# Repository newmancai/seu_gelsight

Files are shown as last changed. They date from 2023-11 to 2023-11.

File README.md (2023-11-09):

# Gelsight for Baxter Modified Robots

该资源库包含东南大学GelSight的制作、baxter改装机械手模型和采集数据集的c代码。这些代码可实现基本功能，例如查看和保存来自这些设备的数据（图像或视频）。

指导老师：东南大学钱堃

## Gelsight制作

参考gelsight与digit下的Gelsight制作说明
4led.SLDPRT为支架模型

## baxter机械手改装

参考baxter改装模型
gripper_modified_asm.stp为本次使用的改装机械手

## 采集数据集

### requirements

```sudo
sudo apt install ffmpeg
sudo apt install gpac
```

### Linux

``Python 3.8 or above``

### 运行

连接上锐尔摄像头

```sudo
ls /dev/video*
```

查看最新的两个路径（如video2,video3）
将video/encode_video.c中的摄像头的设备文件更改为/dev/video2

```sudo
cd video
gcc -g -O0 encode_video.c -lavformat -lavutil -lavdevice  -lavcodec -o encode_video.exe
./encode_video.exe或者(python photo.py)
```

下面是瓶子全空摇晃采集的视频
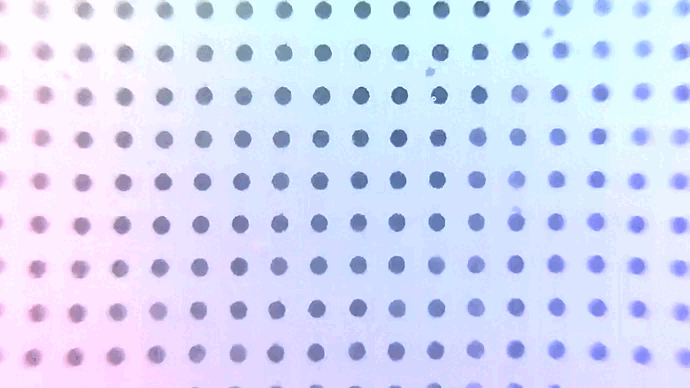
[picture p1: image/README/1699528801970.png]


## 联系我们

本软件包为东南大学大四16个课时课程设计的参考。如有任何问题/意见/建议，请联系 213203742@seu.edu.cn

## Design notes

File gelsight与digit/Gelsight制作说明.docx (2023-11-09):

Gelsight制作说明

一、材料购买

材料 | 用途 | 购买链接 | 备注
AB胶 | 透明膜制作
白色油墨、固化剂、稀释剂 | 膜白色表面涂层 | https://item.taobao.com/item.htm?spm=a1z09.2.0.0.4a312e8dLXXJ9j&id=594951473152&_u=b2095hi08209b4
3*3cm亚克力板 | 支撑 | https://item.taobao.com/item.htm?spm=a1z09.2.0.0.4a312e8dLXXJ9j&id=571400732683&_u=b2095hi08252ef | 3mm（优先），4mm
支撑结构 | 3D打印 | https://item.taobao.com/item.htm?spm=a1z09.2.0.0.4a312e8dLXXJ9j&id=660721591383&_u=b2095hi08253ca
5V灯带 | 照明 | https://item.taobao.com/item.htm?spm=a1z09.2.0.0.4a312e8dLXXJ9j&id=713155284856&_u=b2095hi08211f5
杜邦线 | 连接线
鱼眼相机 | 摄像头 | https://item.taobao.com/item.htm?spm=a1z09.2.0.0.4a312e8dLXXJ9j&id=525170536877&_u=b2095hi082c7ce | 无畸变镜头
PH2.0接线 | 摄像头连接线 | https://item.taobao.com/item.htm?spm=a1z09.2.0.0.4a312e8dLXXJ9j&id=18844977013&_u=b2095hi082d0dc
Usb公头4芯 | 摄像头连接线 | https://detail.tmall.com/item.htm?id=626045240070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 | 红5V黑GND绿DP白DM（仅对应购买链接）
小螺栓 | 固定摄像头与支撑结构
大螺栓 | 固定支撑结构与机器人手爪

注：购买链接仅为可用链接

二、膜制作

1、透明膜制作

AB胶1:1混合，搅拌，使用针管吸取混合溶液至模具中（6ml对应膜厚8mm），静置消除气泡，气泡消除后烤箱90℃加热30min

2、膜白色表面涂层

白色油墨与稀释剂1:4混合，搅拌，加入1滴固化剂，使用喷枪均匀喷涂在膜不平整的一面（透明膜制作时与空气接触的面），晾干

3、连接亚克力板

未喷涂白色涂层的面与亚克力板压紧，确保接触面无气泡

三、支撑结构

1、3灯带支撑结构

支撑摄像头：见附件3led.SLDPRT 3led.STL

保护摄像头：见附件protect.STL（stl文件尺寸与实际尺寸相比小10倍，打印时需放大）

2、4灯带支撑结构

支撑摄像头：见附件4led.SLDPRT 4led.STL（本次未上传）

保护摄像头：同上

注：实测发现，支撑摄像头结构中亚克力板的固定结构对于3D打印强度要求较高，否则亚克力板卡进固定结构时会使得固定结构折断

四、组装（以3灯带为例）

1、亚克力板卡入对应固定结构

2、5V灯条正*3、USB线5V、摄像头PH2.0接线5V焊接在一起

3、5V灯条负*3、USB线GND、摄像头PH2.0接线GND焊接在一起

4、摄像头PH2.0接线DP与USB线DP线焊接在一起、摄像头PH2.0接线DM与USB线DM线焊接在一起

5、灯带布局：红色灯带与蓝色灯带相对

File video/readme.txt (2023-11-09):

sudo apt install gpac
sudo apt install ffmpeg
gcc -g -O0 encode_video.c -lavformat -lavutil -lavdevice  -lavcodec -o encode_video.exe
./encode_video.exe或者(python photo.py)

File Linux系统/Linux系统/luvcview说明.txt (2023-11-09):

在桌面Linux系统上可直接从网络获取luvcview应用
如在ubuntu系统： apt-get install luvcview
运行：luvcview -d /dev/video0 -s 1280x720

查看luvcview的参数：luvcview --help

在PC机编译luvcview源码：
解压luvcview_0.2.4.orig.tar.gz
执行make

需要系统里有X11和SDL库，根据系统版本不同，可能要修改头文件：
#include <linux/videodev.h>  -->   #include <linux/videodev2.h>

其中v4l2uvc.c是最经典的V4L2代码，建议开发者直接拿这个文件中的接口函数使用，参见我们写的“MJPEG录像代码”

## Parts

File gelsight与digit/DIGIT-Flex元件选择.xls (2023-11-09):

备注 | Name | Description | Designator | Quantity | Manufacturer 1 | Manufacturer Part Number 1 | 最终选择 | 来源
数量与DIGIT实物不太符合，实物贴了5个 | ARGB1313HS | ARGB1313HS | D1, D2, D3 | 3 | Stanley Electric | ARGB1313HS-TR | ARGB1313HS-TR | https://item.taobao.com/item.htm?spm=a1z09.2.0.0.e8cd2e8d9dXkha&id=550657882868&_u=b2095hi0825007
 | DF37B-16DP |  | P1 | 1 | Hirose | DF37B-16DP-0.4V(53) | DF37B-16DP-0.4V | https://item.taobao.com/item.htm?spm=a1z09.2.0.0.e8cd2e8d9dXkha&id=562808093080&_u=b2095hi0820544

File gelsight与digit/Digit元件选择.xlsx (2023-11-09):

备注 | Comment | Description | Designator | Manufacturer1 | ManufacturerPartNumber1 | 元件编号 | 元器件来源 | 购买链接
 | MCR01MZPJ103 | ChipResistor,10KOhm,+/-5%,63mW,-55to155degC,0402(1005Metric),RoHS,TapeandReel | R2,R3,R6 | Rohm | MCR01MZPJ103 | C881063 | 立创商城
 | 100nF35V | 100nF35V±20% | C1,C3,C4,C6,C7,C8,C10,C11,C12,C13,C17,C19,C21,C22,C23,C25,C26 | TDK | C1005X7R1V104M | C181044 | 立创商城
 | 1uF6.3V | 1uF6.3V±10% | C16,C18,C20,C27,C28,C29,C30 | KyoceraAVX | 04026D105KAT2A | C5240378 | 立创商城
编号（C4355529）对应的器件丝印是（FT900Q-C-T），收到实物丝印是（FT900Q），售卖者表示正版 | FT900Q-C-R | FT900EmbeddedMicrocontroller,supportbothCANBusandEthernetfeatures,-40to+85degC,100-PinQFN,Pb-Free,TapeandReel | U1 | FTDI | FT900Q-R | C4355529 | 邮寄 | 微信：HLJ07035758
 | OVM7692 | CMOSwithProcessorImageSensor640Hx480V1.75µmx1.75µm | U2 | OmniVisionTechnologies | OVM7692-RAAA | C9900025065 | 邮寄 | https://item.taobao.com/item.htm?spm=a1z09.2.0.0.e8cd2e8d9dXkha&id=696075605241&_u=b2095hi08268cc
该选型可能错误，见文档说明 | ABM10-25.000MHZ-D30-T3 | 12MHz±25ppmCrystal18pF150Ohms4-SMD,NoLead | X1 | ECSInternational | ECS-120-18-36-AGM-TR | C117876 | 立创商城
 | 1KΩ5% | 1KΩ0.063W±5% | R1,R13,R14 | Yageo | RC0402JR-071KL | C11702 | 立创商城
 | DF37NB-16DS-0.4V | 16PositionConnectorReceptacle,CenterStripContactsSurfaceMountGold | P1 | Hirose | DF37NB-16DS-0.4V(51) | C2764729 | 邮寄 | 产品已下架
 | AP7343-33W5-7 | LinearVoltageRegulatorIC1Output300mASOT-25 | U3 | DiodesIncorporated | AP7343-33W5-7 | C460383 | 立创商城
 | 82Ω5%0.063W | 82R0.063W±5% | R9 | Panasonic | ERJ-2GEJ820X | C352387 | 立创商城
 | 18pF10V | 18pF10V±10% | C14,C15 | VishayVitramon | VJ0402A180KXQCW1BC | C1883107 | 邮寄 | https://item.taobao.com/item.htm?spm=a1z09.2.0.0.e8cd2e8d9dXkha&id=732051831113&_u=b2095hi082584e
 | 10uF6.3V | 10uF6.3V±20% | C2,C5 | TDK | C1005X5R0J106M050BC | C15525 | 立创商城
 | 270Ω5%0.063W | 270R0.063W±5% | R8,R10,R12 | Panasonic | ERJ-2GEJ271X | C911980 | 立创商城
 | 12KΩ1%0.063W | 12KΩ0.063W±1% | R4,R5 | Yageo | RC0402FR-0712KL | C881068 | 立创商城
 | 4.7uF10V | 4.7uF10V±10% | C9,C24 | KEMET | C0603C475K8PACTU | C380324 | 立创商城
编号（C232592）对应的器件丝印是（BC847CDXV6T1G），收到实物丝印是（1GY） | BC847CDXV6T5G | DualGeneralPurposeTransistors,NPN,6-PinSOT-563,Pb-Free,TapeandReel | Q1,Q2 | ONSemiconductor | BC847CDXV6T1G | C232592 | 邮寄 | 产品已下架
 | 100Ω5%0.063W | 100R0.063W±5% | R7 | VishayDale | CRCW0402100RJNED | C176111 | 立创商城
 | 150Ω5%0.063W | 150R0.063W±5% | R11 | VishayDale | CRCW0402150RJNED | C881296 | 立创商城
 | LQM18PN3R3MGHD | Inductor | L1,L2,L3 | Murata | LQM18PN3R3MGHD | C383399 | 立创商城
编号（C125810）对应的器件丝印是（LP3992IMFX-1.5/NOPB），收到实物丝印是（LFHB） | LP3992IMFX-1.5/NOPB | Micropower1.5VCMOSVoltageRegulatorwithShutdownControl,5-pinSOT-23,Pb-Free | U4 | TINationalSemiconductor | LP3992IMFX-1.5/NOPB | C125810 | 邮寄 | https://item.taobao.com/item.htm?spm=a1z09.2.0.0.e8cd2e8d9dXkha&id=708270094718&_u=b2095hi0829e42
 | USB3140-30-0230-1-C | MicroUSBReceptacle,TypeB,SMT,Vertical,withThrough-HoleShellStakes,-30to85degC,5-PinSMD,RoHS,TapeandReel | J1 | GlobalConnectorTechnology | USB3140-30-0230-1-C | C9900024888 | 邮寄 | https://item.taobao.com/item.htm?spm=a1z09.2.0.0.e8cd2e8d9dXkha&id=708983181332&_u=b2095hi0826603

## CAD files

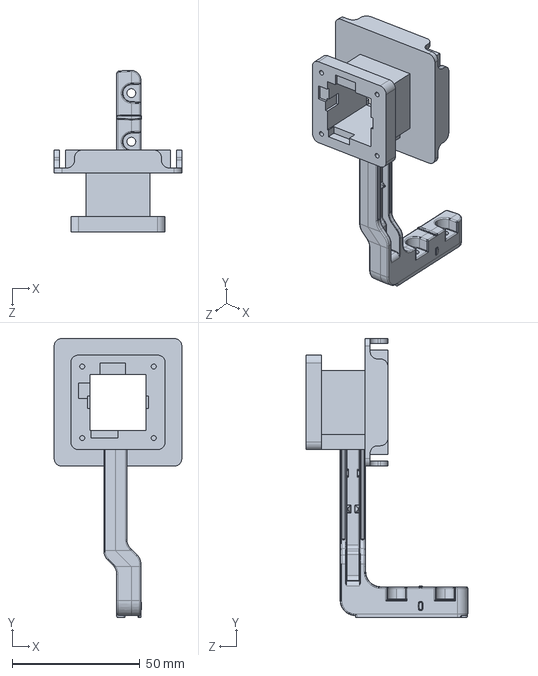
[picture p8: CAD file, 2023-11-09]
baxter改装模型/baxter改装模型/gripper_modified_asm.STEP
50.0 x 109.2 x 63.2 mm

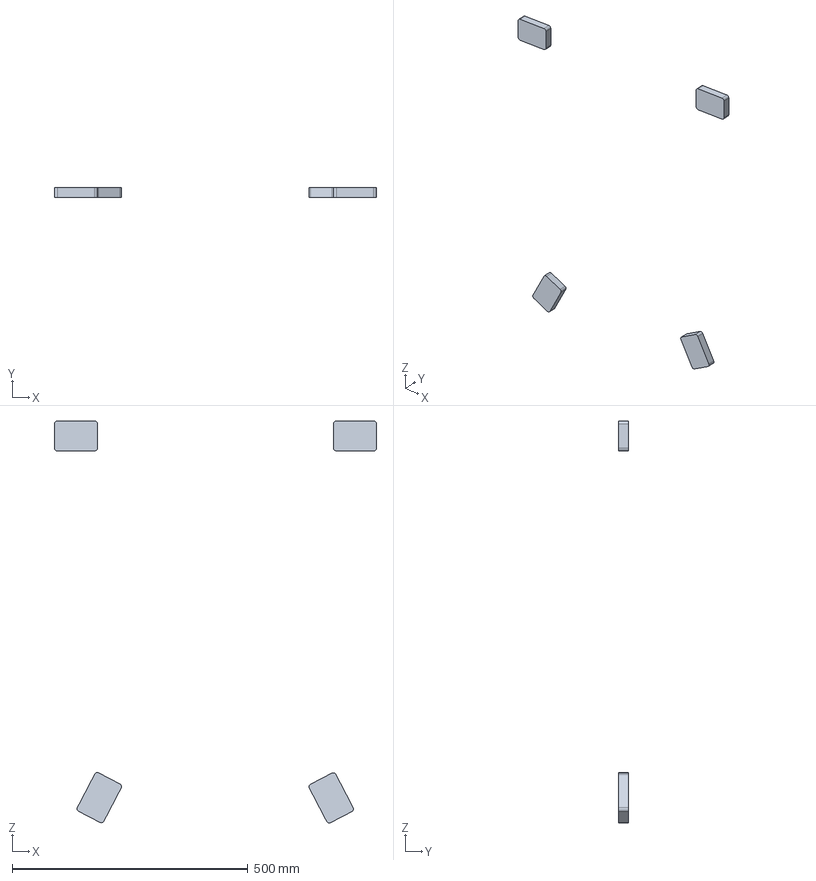
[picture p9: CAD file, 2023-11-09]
baxter改装模型/baxter改装模型/baxter_asm.stp
684.1 x 21.0 x 852.7 mm
PEDESTAL-7
PEDESTAL-12
PEDESTAL-24
PEDESTAL-36
PEDESTAL-48
PEDESTAL-60
PEDESTAL-72
PEDESTAL-82
PEDESTAL-94
PEDESTAL-106
PEDESTAL-118
PEDESTAL-130
PEDESTAL-142
PEDESTAL-154
PEDESTAL-166
PEDESTAL-178
PEDESTAL-188
PEDESTAL-200
PEDESTAL-212
PEDESTAL-224
PEDESTAL-236
PEDESTAL-248
PEDESTAL-260
PEDESTAL-272
PEDESTAL-284
PEDESTAL-294
PEDESTAL-304
PEDESTAL-314
PEDESTAL-324
PEDESTAL-334
PEDESTAL-344
PEDESTAL-356
PEDESTAL-368
PEDESTAL-380
PEDESTAL-392
PEDESTAL-404
PEDESTAL-416
PEDESTAL-428
PEDESTAL-440
PEDESTAL-452
PEDESTAL-464
PEDESTAL-474
PEDESTAL-486
PEDESTAL-498
PEDESTAL-510
PEDESTAL-522
PEDESTAL-534
PEDESTAL-546
PEDESTAL-556
PEDESTAL-568
PEDESTAL-580
PEDESTAL-592
PEDESTAL-604
PEDESTAL-616
PEDESTAL-628
PEDESTAL-640
PEDESTAL-650
PEDESTAL-662
PEDESTAL-674
PEDESTAL-686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

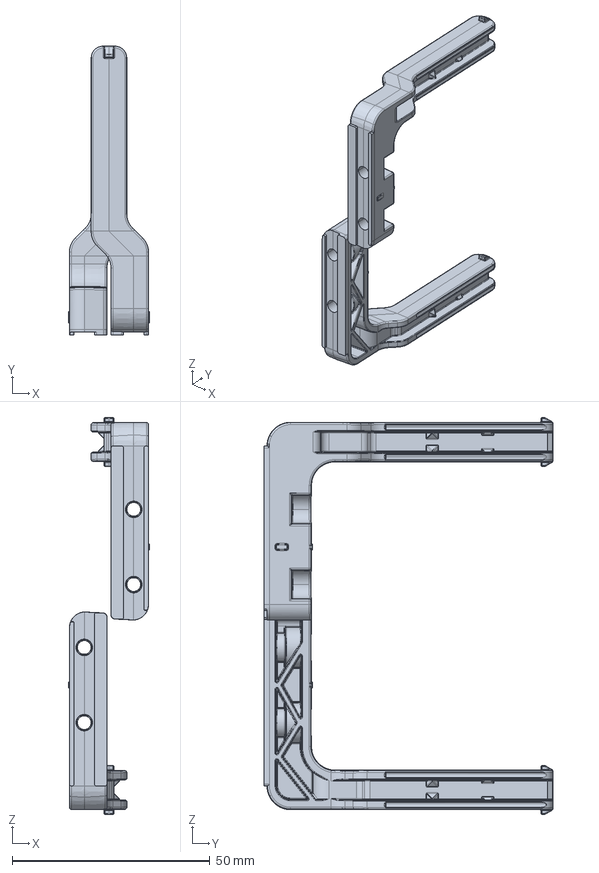
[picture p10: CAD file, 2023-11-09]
baxter改装模型/baxter改装模型/gripper_asm.stp
20.5 x 73.0 x 100.3 mm
J12
J13 x 2

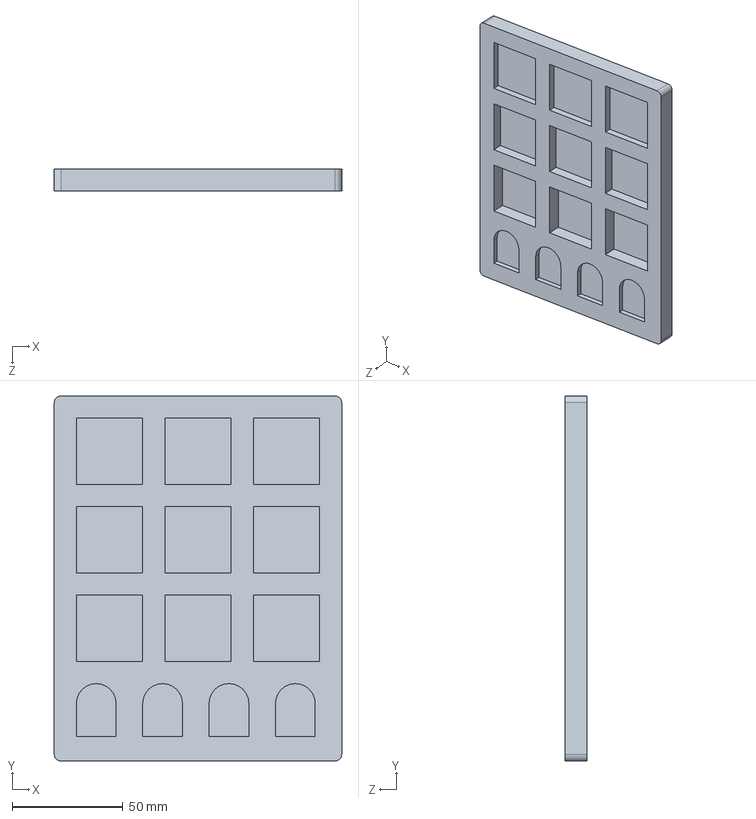
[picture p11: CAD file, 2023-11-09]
gelsight与digit/模具.SLDPRT
130.0 x 165.0 x 10.0 mm

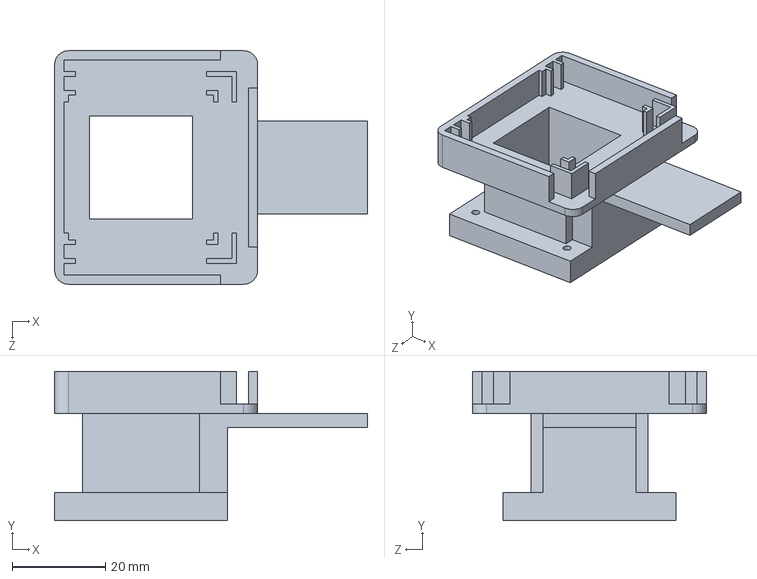
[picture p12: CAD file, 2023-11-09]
gelsight与digit/3led.SLDPRT
67.0 x 32.0 x 50.0 mm

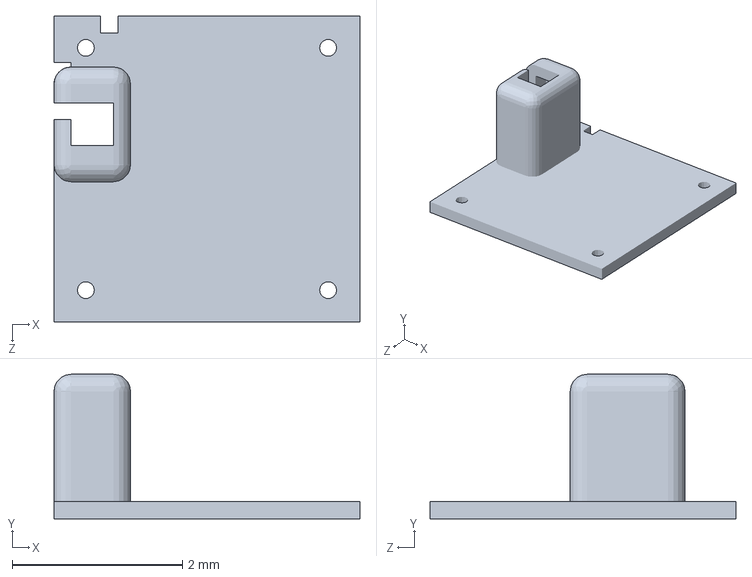
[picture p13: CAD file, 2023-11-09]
gelsight与digit/protect.SLDPRT
3.60 x 1.70 x 3.60 mm

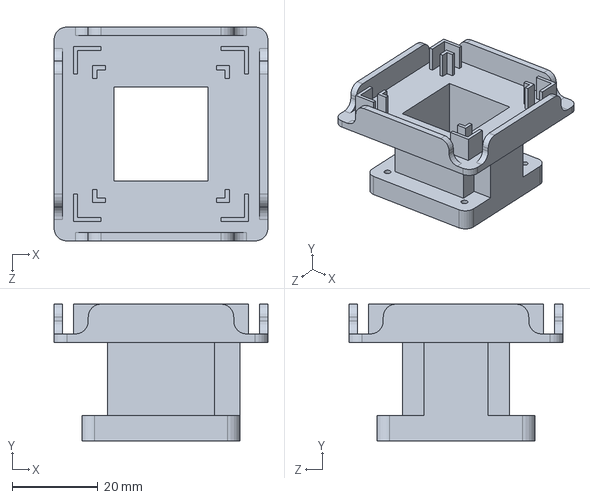
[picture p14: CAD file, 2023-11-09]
gelsight与digit/4led.SLDPRT
50.0 x 32.0 x 50.0 mm

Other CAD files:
gelsight与digit/手机支架.SLDPRT
baxter改装模型/baxter改装模型/gripper_asm.SLDASM
baxter改装模型/baxter改装模型/gripper_modified_asm.SLDPRT
gelsight与digit/3led.STL
gelsight与digit/4led.STL
gelsight与digit/protect.stl
gelsight与digit/模具.STL

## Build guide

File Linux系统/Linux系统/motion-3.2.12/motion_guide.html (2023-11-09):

# Motion Guide - One Large Document.

This version of the Guide is made for inclusion in the Motion download package for off line reading.

If you read this document from the distribution package of Motion or from some not up to date mirror you should know that the URL for the always up to date version is http://www.lavrsen.dk/foswiki/bin/view/Motion/MotionGuide. If you are already on the Foswiki based Motion site clicking the link just mentioned will lead you to the index page for the Motion Guide documents.

This topic consists of the following subtopics: MotionOverview (http://www.lavrsen.dk/foswiki/bin/view/Motion/MotionOverview), KnownProblems (http://www.lavrsen.dk/foswiki/bin/view/Motion/KnownProblems), InstallOverview (http://www.lavrsen.dk/foswiki/bin/view/Motion/InstallOverview), PrepareInstall (http://www.lavrsen.dk/foswiki/bin/view/Motion/PrepareInstall), ConfigureScript (http://www.lavrsen.dk/foswiki/bin/view/Motion/ConfigureScript), MakeInstall (http://www.lavrsen.dk/foswiki/bin/view/Motion/MakeInstall), UpgradingFromOlderVersion (http://www.lavrsen.dk/foswiki/bin/view/Motion/UpgradingFromOlderVersion), RunningMotionConfigFiles (http://www.lavrsen.dk/foswiki/bin/view/Motion/RunningMotionConfigFiles), CommandLineOptions (http://www.lavrsen.dk/foswiki/bin/view/Motion/CommandLineOptions), ConfigFileOptions (http://www.lavrsen.dk/foswiki/bin/view/Motion/ConfigFileOptions), SignalsKill (http://www.lavrsen.dk/foswiki/bin/view/Motion/SignalsKill), ErrorLogging (http://www.lavrsen.dk/foswiki/bin/view/Motion/ErrorLogging), CaptureDeviceOptions (http://www.lavrsen.dk/foswiki/bin/view/Motion/CaptureDeviceOptions), MotionDetectionSettings (http://www.lavrsen.dk/foswiki/bin/view/Motion/MotionDetectionSettings), ImageFileOutput (http://www.lavrsen.dk/foswiki/bin/view/Motion/ImageFileOutput), TuningMotion (http://www.lavrsen.dk/foswiki/bin/view/Motion/TuningMotion), MpegFilmsFFmpeg (http://www.lavrsen.dk/foswiki/bin/view/Motion/MpegFilmsFFmpeg), SnapshotsWebCam (http://www.lavrsen.dk/foswiki/bin/view/Motion/SnapshotsWebCam), TextFeatures (http://www.lavrsen.dk/foswiki/bin/view/Motion/TextFeatures), AdvancedFilenames (http://www.lavrsen.dk/foswiki/bin/view/Motion/AdvancedFilenames), ConversionSpecifiers (http://www.lavrsen.dk/foswiki/bin/view/Motion/ConversionSpecifiers), WebcamServer (http://www.lavrsen.dk/foswiki/bin/view/Motion/WebcamServer), RemoteControlHttp (http://www.lavrsen.dk/foswiki/bin/view/Motion/RemoteControlHttp), ExternalCommands (http://www.lavrsen.dk/foswiki/bin/view/Motion/ExternalCommands), TrackingControl (http://www.lavrsen.dk/foswiki/bin/view/Motion/TrackingControl), UsingDatabases (http://www.lavrsen.dk/foswiki/bin/view/Motion/UsingDatabases), LoopbackDevice (http://www.lavrsen.dk/foswiki/bin/view/Motion/LoopbackDevice).

- Motion Guide - Installation
  - Motion Overview
    - What is Motion?
    - How do I get Motion and what does it cost?
    - Maintenance and Support
    - Which version to download and use?
    - What features does Motion have?
    - FreeBSD
    - MacOSX
    - Documentation
    - Supported Hardware
  - Known Problems
  - How do I install Motion?
  - Preparation For Install
  - Configure Script
  - Make
    - Make Install
    - Un-install
    - Additional Make Options
  - Upgrading From Older Version
  - Running Motion
    - Important Definitions
    - The Config Files
  - Command Line Options
  - Config File Options
    - Options in Alphabetical Order.
    - Obsolete Options
  - Signals (sent with e.g. kill command)
  - Error Logging
- Motion Guide - Basic Features
  - Capture Device Options - The Basic Setup
  - video4linux (V4L) devices
    - auto_brightness
    - brightness
    - contrast
    - framerate
    - frequency
    - height
    - hue
    - input
    - minimum_frame_time
    - norm
    - rotate
    - saturation
    - tunerdevice
    - v4l2_palette
    - videodevice
    - width
  - Network Cameras
    - netcam_http
    - netcam_proxy
    - netcam_tolerant_check
    - netcam_url
    - netcam_userpass
  - Round Robin feature
    - roundrobin_frames
    - roundrobin_skip
    - switchfilter
  - Motion Detection Settings
    - area_detect
    - despeckle
    - gap
    - lightswitch
    - mask_file
    - max_mpeg_time
    - minimum_motion_frames
    - noise_level
    - noise_tune
    - output_all
    - post_capture
    - pre_capture
    - smart_mask_speed
    - threshold
    - threshold_tune
  - Image File Output
    - output_motion
    - output_normal
    - ppm
    - quality
  - Tuning Motion
  - Generating MPEG films with ffmpeg
    - ffmpeg_bps
    - ffmpeg_cap_motion
    - ffmpeg_cap_new
    - ffmpeg_deinterlace
    - ffmpeg_timelapse
    - ffmpeg_timelapse_mode
    - ffmpeg_variable_bitrate
    - ffmpeg_video_codec
  - Snapshots - The Traditional Periodic Web Camera
    - snapshot_interval
  - Text Features
    - locate
    - text_changes
    - text_double
    - text_event
    - text_left
    - text_right
  - Advanced Filenames
    - ffmpeg_filename (now called movie_filename)
    - jpeg_filename
    - movie_filename
    - snapshot_filename
    - target_dir
    - timelapse_filename
  - Conversion Specifiers for Advanced Filename and Text Features
  - Webcam Server
    - webcam_limit
    - webcam_localhost
    - webcam_maxrate
    - webcam_motion
    - webcam_port
    - webcam_quality
  - Remote Control with http
    - control_authentication
    - control_html_output
    - control_localhost
    - control_port
  - External Commands
    - on_area_detected
    - on_camera_lost
    - on_event_end
    - on_event_start
    - on_motion_detected
    - on_movie_end
    - on_movie_start
    - on_picture_save
    - quiet
    - What happened to mail and sms?
      - Sending email at start of event
      - Sending SMS at start of event
- Motion Guide - Special Features
  - Tracking Control
    - Tracking Feature with Logitech Quickcam Sphere/Orbit
    - track_auto
    - track_iomojo_id
    - track_maxx
    - track_maxy
    - track_motorx
    - track_motory
    - track_move_wait
    - track_port
    - track_speed
    - track_step_angle_x
    - track_step_angle_y
    - track_stepsize
    - track_type
  - Using Databases
    - sql_log_image
    - sql_log_mpeg
    - sql_log_snapshot
    - sql_log_timelapse
    - sql_query
  - MySQL
    - mysql_db
    - mysql_host
    - mysql_password
    - mysql_user
  - PostgreSQL
    - pgsql_db
    - pgsql_host
    - pgsql_password
    - pgsql_port
    - pgsql_user
  - Video4Linux Loopback Device
    - motion_video_pipe
    - video_pipe

# Motion Guide - Installation

## Motion Overview (http://www.lavrsen.dk/foswiki/bin/view/Motion/MotionOverview)

### What is Motion?

Motion is a program that monitors the video signal from one or more cameras and is able to detect if a significant part of the picture has changed. Or in other words, it can detect motion.

The program is written in C and is made for the Linux operating system.

Motion is a command line based tool. It has absolutely no graphical user interface. Everything is setup either via the command line or via a set of configuration files (simple ASCII files that can be edited by any ASCII editor).

The output from motion can be:

- jpg files
- ppm format files
- mpeg video sequences

### How do I get Motion and what does it cost?

Motion is an open source type of project. It does not cost anything. Motion is published under the GNU GENERAL PUBLIC LICENSE (http://www.gnu.org/licenses/gpl.html) (GPL) version 2 or later. It may be a bit difficult to understand all the details of the license text (especially if your first language is not English). It means that you can get the program, install it and use it freely. You do not have to pay anything and you do not have to register anywhere or ask the author or publisher for permission. The GPL gives you both rights and some very reasonable duties when it comes to copying, distribution and modification of the program. So in very general terms you do not have to worry about licensing as a normal hobby user. If you want to use Motion in a commercial product, if you want to distribute either modified or original versions of Motion - for free or for a fee, you should read the license carefully. For more information about free software and the GPL, I encourage you to study the very interesting documents about the subject available the of the Free Software Foundation pages about the Philosophy of the GNU Project (http://www.gnu.org/philosophy/philosophy.html).

### Maintenance and Support

Both Motion and the Motion Guide are written by people that do all this as a hobby and without asking for any payments or donations. We have a life other than developing Motion and its documentation. This means that bugfixes and updates to this guide are done as our time and families allow it. You are however encouraged to participate and contribute in a very active mailing list (http://www.lavrsen.dk/foswiki/bin/view/Motion/MailingList). It is a list with a very "positive attitude" and with many contributors that propose features, post patches, discuss problems and patiently answer newbie questions with a very positive spirit. Expect 1-10 emails per day.

To get motion direct your browser to the Motion Homepage (http://www.lavrsen.dk/foswiki/bin/view/Motion/WebHome).

On the Download Files (http://www.lavrsen.dk/foswiki/bin/view/Motion/DownloadFiles) page you will find a links to the latest stable version both as sources and binaries for some of the most popular Linux distributions. You will also find links to development versions. Snapshot releases are special test releases that are normally very stable. Every day a Motion Daily Source Snap (http://www.lavrsen.dk/foswiki/bin/view/Motion/MotionDailySourceSnap) is created from the Motion Subversion (http://www.lavrsen.dk/foswiki/bin/view/Motion/MotionSubversion)

Motion was originally written by Jeroen Vreeken who still actively participates in the development of Motion and later Folkert van Heusden continued as a lead programmer with Kenneth Lavrsen responsible for Motion Guide, website and releases on Sourceforge.

From version 3.1.12 Motion is now project managed entirely by Kenneth Lavrsen, and the project now shift towards being developed by many contributers.

For support we encourage you to join the mailing list instead of writing to Jeroen, Folkert or Kenneth directly. We are all very active on the mailing list and by using the mailing list much more users will have benefit of the answers. Newbies and stupid questions are welcome on the list. Contributions in the form of patches are also very welcome on the mailing list.

### Which version to download and use?

Versions 3.2.X are the current version. There is at the moment no development branch. The versions 3.1.X ended at 3.1.20 and there will be no more 3.1.X releases. If you use use a version older than 3.2.X you are encouraged to update.

Since 3.1.13 quite many options have been renamed to make setting up Motion easier. From 3.1.17-18 some unfinished features have been removed. The Berkeley mpeg feature is now removed because the ffmpeg feature is now mature and much better working. At version 3.1.18 a new network camera feature was introduced replacing the old cURL based netcam code and introducing support of mjpeg streaming cameras. However this new code was quite difficult to get stable. During the development of 3.2.2 the network camera code was totally rewritten again learning from our experience and now finally it seems to be stable.

Motion is included in Debian, while Ubuntu and RPM users can find binary packages on the Motion Sourceforge file download page.

### What features does Motion have?

See more description at the Motion Homepage (http://www.lavrsen.dk/foswiki/bin/view/Motion/WebHome).

- Taking snapshots of movement
- Watch multiple video devices at the same time
- Watch multiple inputs on one capture card at the same time
- Live streaming webcam (using multipart/x-mixed-replace)
- Real time creation of mpeg movies using libraries from ffmpeg
- Take automated snapshots on regular intervals
- Take automated snapshots at irregular intervals using cron
- Executing external program when detecting movement
- Execute external program at the beginning of an event of several motion detections.
- Execute external program at the end of an event of several motion detections.
- Execute external program when a picture is saved.
- Execute external program when a movie mpeg is created (opened)
- Execite external program when a movie mpeg ends (closed)
- Motion tracking
- Feed events to an MySQL or PostgreSQL database.
- Feed video back to a video4linux loopback for real time viewing
- Web interface using Motion Related Projects (http://www.lavrsen.dk/foswiki/bin/view/Motion/RelatedProjects) such as motion.cgi (http://www.lavrsen.dk/foswiki/bin/view/Motion/MotionCGI), Kenneths Webcam Package (http://www.lavrsen.dk/foswiki/bin/view/Motion/KennethsWebcamPackage), Kevins Webpage (http://www.lavrsen.dk/foswiki/bin/view/Motion/KevinsWebpage), X-Motion (http://www.lavrsen.dk/foswiki/bin/view/Motion/XMotionTool) and many more.
- User configurable and user defined on screen display.
- Control via simple web interface.
- Automatic noise and threshold control
- Ability to control the pan/tilt of a Logitech Sphere (or Orbit) camera
- Highly configurable display of text on images.
- High configurable definition of path and file names of the stored images and films.

You can find more information and links at the Motion Homepage (http://www.lavrsen.dk/foswiki/bin/view/Motion/WebHome).

### FreeBSD

Motion is originally developed for Linux and it is still mainly developed and supported for this platform. From version 3.1.15 an experimental port has been made by Angel Carpintero. Not all features of Motion are supported at this time and it still needs a lot of test time on different hardware. Angel is very interested in feedback. Join the Motion Mailing List and give your feedback there. Patches for bugfixes and for enabling the missing features are very welcome. The rest of this guide is still mainly targeted for Linux users. Follow this topic to Install FreeBSD (http://www.lavrsen.dk/foswiki/bin/view/Motion/FreeBSD).

### MacOSX

From Motion version 3.2.4 it is now also possible to build and install Motion under MacOSX (http://www.lavrsen.dk/foswiki/bin/view/Motion/MacOSX). Feature set it the same as for FreeBSD. See the MacOSX (http://www.lavrsen.dk/foswiki/bin/view/Motion/MacOSX) topic for specific help how to install Motion and its dependencies on MacOSX (http://www.lavrsen.dk/foswiki/bin/view/Motion/MacOSX). Again this port has been contributed by Angel Carpintero.

### Documentation

You have the following sources of information:

- This Motion Guide (http://www.lavrsen.dk/foswiki/bin/view/Motion/MotionGuide).
- The Frequently Asked Questions (http://www.lavrsen.dk/foswiki/bin/view/Motion/FrequentlyAskedQuestions)
- The author of the program has written a description of the technology behind motion (http://www.lavrsen.dk/foswiki/bin/view/Motion/MotionTechnology).
- The man page. After installation simply write man motion
- The default motion.conf file (motion-dist.conf) that comes with the package.

### Supported Hardware

Input devices: Here we are thinking about the cameras.

Motion supports video input from two kinds of sources.

Standard video4linux devices (e.g. /dev/video0). Motion has no drivers for cameras. Installing the camera itself is outside the scope of this document. But here are some nice links.

- Driver for USB Philips cameras (and more) (http://www.saillard.org/pwc/) This driver is a fork of the old pcw(x) driver which got kicked out of the kernel. (see: http://www.smcc.demon.nl/webcam/). See also the new PWC Documentation Site (http://www.lavrsen.dk/foswiki/bin/view/PWC/WebHome) which is hosted in this wiki.
- BTTV Driver (http://bytesex.org/bttv/index.html) (capture cards). Part of many distributions now.
- OV511 (http://alpha.dyndns.org/ov511/) based USB cameras are supported as standard by newer Kernels.
- kernel driver for USB cameras based on Sunplus spca50 (http://spca50x.sourceforge.net/spca50x.php)
- rivatv.sourceforge.net Driver for tv/composite/svideo input with most Nvidia based video cards. Network cameras (which are actually cameras with a built in web server that can be connected directory to your network).
- Axis Communications (http://www.axis.com/)

## Known Problems (http://www.lavrsen.dk/foswiki/bin/view/Motion/KnownProblems)

See also the Frequently Asked Questions (http://www.lavrsen.dk/foswiki/bin/view/Motion/FrequentlyAskedQuestions) and Bug Reports (http://www.lavrsen.dk/foswiki/bin/view/Motion/BugReports) for known open bugs.

Kernel 2.6 and pwc. Note that for kernel 2.6 there is a new release of the Philips WebCam (pwc) drivers 10.0.X. It is recommended to install this. At the time of this being written the 2.6.12+ kernels have a version of pwc built-in but it is a cripled version which can only support very small picture size. You can however download the latest source code of the pwc driver (at this time 10.0.11) and build it without having to rebuild your kernel. But you will need to have either the kernel sources or a special kernel-header package installed to compile it. See Installation of PWC (http://www.lavrsen.dk/foswiki/bin/view/PWC/InstallationOfPWC) page which is also hosted in this wiki.

If you use use a Logitech Quickcam Orbit or Sphere using the driver pwc/pwcx and kernel 2.6.X you should replace the file in the Motion sources called pwc-ioctl.h with the one that comes with the your pwc version. Motion is shipped with 3 versions of pwc-ioctl.h-VERSION. Rename the one that fits your major pwc version number best to pwc-ioctl.h (after renaming the current to something else). There has been some small adjustments in the API that requires that you have the right header file.

Camera picture dimensions must be multiple of 16 Dimentions of camera image must have both height and width that are a multiple of 16. Thís is normally not a problem. All standard sizes like 640, 480, 352, 320, 288, 240, ...etc are multiples of 16. But if you intend to monitor a network camera which is saving jpeg images you may have to pay attention to the dimensions of the picture.

ffmpeg_filename has changed name to movie_filename The 3.2.5 release contains a motion_guide and man page in which it was forgotten to change ffmpeg_filename to movie_filename. Please note that the option that defines the filenames for mpeg movies is now called movie_filename. This change is made because we may soon implement alternatives to ffmpeg and then ffmpeg_filename will be a bad name. This is fixed in release 3.2.5.1.

error: `time_current_frame' undeclared (first use in this function) A bug in 3.2.5 and 3.2.5.1 where a bugfix related to snapshot feature has created a new bug when you compile Motion without ffmpeg libs installed. This is fixed in 3.2.6.

## How do I install Motion (http://www.lavrsen.dk/foswiki/bin/view/Motion/InstallOverview)?

Motion is mainly distributed as source files that you must compile yourself. There is also an RPM made on Fedora Core 3. And Debian packages are available for selected versions.

The short overview of the steps to install Motion from sources.

- Preparation: Motion uses a number of shared libraries that must be installed on your computer before you can build Motion. The needed shared libraries depends on the features you wish to use. Features network camera, ffmpeg, MySQL and PostgreSQL needs specific shared libraries installed. See preparation section for more information.
- Download the motion source files (distributed as tar'ed and compressed files). Place the file in a place of your own choice.
- Untar and uncompress the file to the place you want the program installed. Editor recommends placing the motion source file directory in /usr/local. If you do not have write access to the /usr/local directory (you are under the mercy of an ignorant system administrator with a severe case of paranoia) - you can install the program in a directory in your home directory. You will then need to read the next section about how to configure before you compile the program. Below is shown the exact commands using version 3.2.X installed in /usr/local as an example (replace /path/to with the actual placement of the tar.gz file).

cd /usr/local
tar -xvzf /path/to/motion-3.2.X.tar.gz
- You will now have created a directory called motion-3.2.X. You can rename it to motion (mv motion-3.1.X motion). I recommend creating a symbolic link to the current version. This way you can more easily experiment with different version simply by changing the link.

ln -s motion-3.2.X motion
- Now change to the new directory

cd motion
- Run configure. You can start with the defaults. If you need to modify the installation parameters you can read the next section.

./configure
- Build the code

make
- Install the code, manual page, etc

make install
- In /etc/motion/etc you will find a file called motion-dist.conf. If it is the first time you install Motion - rename this file to motion.conf and edit as a minimum the settings: videodevice, input, norm, frequency, width, height and target_dir. That should get you going.
- Run the program. To enable more features you must modify the config file.

motion

## Preparation For Install (http://www.lavrsen.dk/foswiki/bin/view/Motion/PrepareInstall)

Note: If you're using SuSE 9.2, you might want to ADDITIONALLY have a look at Compiling on SuSE 9.2 (http://www.lavrsen.dk/foswiki/bin/view/Motion/SuSE92Prep). As mentioned on that page as well, you will still need to read the instructions here as well.

Before you start you may need to install a number of shared libraries that Motion uses. If they are missing the feature will simply normally not be included. Most of these libraries can be found on the CDs of your distribution. A few will have to be downloaded from the Internet. Note that when you install software using pre-compiled binaries (Redhat type RPMs, Debian debs etc) you normally only get what is needed to run the programs themselves. In order to compile other programs from source that uses these pre-compiled libraries you also need to installed the development packages. These are normally called the same name as the package suffixed by -devel or -dev. These development packages contains the header files (xxx.h) that Motion needs to build with the shared libraries. If you build a library from sources you already have these header files. It is recommended to simply install the pre-compiled binary packages and their development brothers.

This is a list of shared libraries used by Motion and the RPM packages that provides them.

Motion will always need these libraries to be built and work

Library (http://www.lavrsen.dk/foswiki/bin/view/Motion/MotionGuideOneLargeDocument;sortcol=0;table=1;up=0) | RPM Packages (http://www.lavrsen.dk/foswiki/bin/view/Motion/MotionGuideOneLargeDocument;sortcol=1;table=1;up=0) | Debian Packages (http://www.lavrsen.dk/foswiki/bin/view/Motion/MotionGuideOneLargeDocument;sortcol=2;table=1;up=0)
libm, libresolv, libdl, libpthread, libc, ld-linux, libcrypt, and libnsl | glibc and glibc-devel | libc6 , libc6-dev ,libglib1.2
libjpeg | libjpeg and libjpeg-devel | libjpeg62 and libjpeg62-dev ( optional libjpeg-mmx-dev )
libz | zlib and zlib-devel | zlib1g and zlib1g-dev

For generating mpeg films with ffmpeg you need this library:
(See also the section Generating MPEG films with ffmpeg (http://www.lavrsen.dk/foswiki/bin/view/Motion/MpegFilmsFFmpeg) for how to install ffmpeg and libavformat/libavcodec)
Motion must be installed with revision 0.4.8 or 0.4.9pre1 of ffmpeg. Motion will also work with later CVS snapshots of ffmpeg but the API of the ffmpeg libraries changes all the time and without warning. If you have problems compiling Motion or with running an RPM of Motion you may try with an older CVS snapshot of ffmpeg. The Motion developers will like to know when ffmpeg changes and breaks Motion so we can fix it. Please file a bug report then with the exact date of the ffmpeg CVS version you have trouble with.

Library (http://www.lavrsen.dk/foswiki/bin/view/Motion/MotionGuideOneLargeDocument;sortcol=0;table=2;up=0) | RPM Packages (http://www.lavrsen.dk/foswiki/bin/view/Motion/MotionGuideOneLargeDocument;sortcol=1;table=2;up=0) | Debian Packages (http://www.lavrsen.dk/foswiki/bin/view/Motion/MotionGuideOneLargeDocument;sortcol=2;table=2;up=0)
libavcodec, libavformat | ffmpeg and ffmpeg-devel or install from source | libavcodec-dev libavcodec0d libavformat-dev libavformat0d (*)

Debian has not provided deb packages for ffmpeg due patent issues. However this is about to change so checkout for availability of newer versions of debian ffmpeg debs. You can build yourself from source or from Christian Marillat website (http://debian-multimedia.org/) or apt repository.

deb http://www.debian-multimedia.org stable main # ( etch )
deb http://www.debian-multimedia.org testing main # ( lenny )
deb http://www.debian-multimedia.org unstable main # ( sid )

Add the suitable line to your /etc/apt/sources.list and run this:

apt-get update ; apt-get -y install libavcodec-dev libavcodec0d libavformat-dev libavformat0d

For logging in MySQL you need this library:

Library (http://www.lavrsen.dk/foswiki/bin/view/Motion/MotionGuideOneLargeDocument;sortcol=0;table=3;up=0) | RPM Packages (http://www.lavrsen.dk/foswiki/bin/view/Motion/MotionGuideOneLargeDocument;sortcol=1;table=3;up=0) | Debian Packages (http://www.lavrsen.dk/foswiki/bin/view/Motion/MotionGuideOneLargeDocument;sortcol=2;table=3;up=0)
libmysqlclient | mysql and mysql-devel | libmysqlclient15-off and libmysqlclient15-dev

For logging in PostgreSQL you need this library:

Library (http://www.lavrsen.dk/foswiki/bin/view/Motion/MotionGuideOneLargeDocument;sortcol=0;table=4;up=0) | RPM Packages (http://www.lavrsen.dk/foswiki/bin/view/Motion/MotionGuideOneLargeDocument;sortcol=1;table=4;up=0) | Debian Packages (http://www.lavrsen.dk/foswiki/bin/view/Motion/MotionGuideOneLargeDocument;sortcol=2;table=4;up=0)
libpq | postgresql-libs and postgresql-devel | libpq-dev and libpq4

## Configure Script (http://www.lavrsen.dk/foswiki/bin/view/Motion/ConfigureScript)

Configure is script that you run to setup the build environment for the C-compiler. It generates the "Makefile" which the program "make" uses to compile and install the software.

To run configure your current directory must be the motion directory. You type

./configure

You can add the parameter ./configure --help to get help on the different switches.

This is walk through of the options.

Option | Description Defaults for the options are specified in brackets [ ] | Editors comment
-h, --help | display this help and exit
--help=short | display options specific to this package | This command shows the options special to motion. Recommended
--help=recursive | display the short help of all the included packages
-V, --version | display version information and exit | Gives no useful information
-q, --quiet, --silent | do not print `checking...' messages | Not very useful. Output to screen is only a few lines anyway.
--cache-file=FILE | cache test results in FILE. [disabled] | No function
-C, --config-cach | alias for `--cache-file=config.cache' | No function
-n, --no-create | do not create output files | Used for testing if other switches produce error - without writing anything to the disk
--srcdir=DIR | find the sources in DIR. [configure dir or `..'] | DIR is a directory path. Editor recommends having the current directory being the motion installation directory and not using this switch. Then it defaults to the same directory as where the configure script is which is the current directory.
Installation directories:

--prefix=PREFIX

install architecture-independent files in PREFIX
[/usr/local]

The default /usr/local means that the executable binary "motion" is installed in /usr/local/bin, the manual page in /usr/local/man/man1, the document files in /usr/local/docs/motion-version, configuration file in /usr/local/etc, and some examples config files in /usr/local/examples/motion-versionEditor recommends keeping this default setting.
If you are experimenting with many parallel versions it may be interesting to set the PREFIX to e.g. /usr/local/motion and then add /usr/local/motion/bin to your search path (or simply cd /usr/local/motion/bin before execution).
This way you can change version just by changing the symbolic link in /usr/local/motion as suggested earlier in this guide.
If you are installing the software on a machine where you have no access to the /usr/local but have write access to a home directory, then you should change this to point to a directory within your home tree.
Example: --prefix=$HOME
--exec-prefix=EPREFIX | install architecture-dependent files in EPREFIX [PREFIX] | If you set this it only defines an alternative installation directory for the executable binary. Note: The executable binary will be placed in a directory "bin" below the directory specified by this option Editor recommends leaving this as default (i.e. not setting it).
--bindir=DIR | user executables [EPREFIX/bin] | With this option you can control exactly in which directory the executable binary is installed. The previous option automatically adds the bin directory. Here you are in fill control.
--sbindir=DIR | System admin executables [EPREFIX/sbin] | Not used by motion. Ignore it.
--libexecdir=DIR | program executables [EPREFIX/libexec] | Not used by motion. Ignore it.
--datadir=DIR | read-only architecture-independent data [PREFIX/share] | Not used by motion. Ignore it.

--sysconfdir=DIR

read-only single-machine data [PREFIX/etc]

This is where motion both installs the default configuration file and also where it later searches for it.
Motion searches for the configuration file "motion.conf" in the following order:

1. Current directory from where motion was invoked
2. $HOME/.motion
3. The sysconfig directory set by this switch. If not defined the default is /usr/local/etc/

Editor recommends leaving this at default. Be careful if you run "make install" again. This will overwrite the motion.conf file that you have edited and experimented with for hours. Make sure to keep a copy in a safe place. Alternatively, copy the working file to the motion base install directory. Then make install will simply copy the same file back again.
--sharedstatedir=DIR | modifiable architecture-independent data [PREFIX/com] | Not used by motion. Ignore it.
--localstatedir=DIR | modifiable single-machine data [PREFIX/var] | Not used by motion. Ignore it.
--libdir=DIR | object code libraries [EPREFIX/lib] | Not used by motion. Ignore it.
--includedir=DIR | C header files [PREFIX/include] | Not used by motion. Ignore it.
--oldincludedir=DIR | C header files for non-gcc [/usr/include] | Not used by motion. Ignore it.
--infodir=DIR | info documentation [PREFIX/info] | Not used by motion. Ignore it.
--mandir=DIR | man documentation [PREFIX/man] | Editor recommends the default.
Optional Packages:
--with-linuxthreads | Use linuxthreads in BSD instead of native phtreads | Only relevant for BSD. In Linux we always use this per default.
--with-pwcbsd | Use pwcbsd based webcams ( only BSD ) | This option allow to build motion to support V4L (http://www.lavrsen.dk/foswiki/bin/view/Motion/V4L)/V4L2 in BSD. HowtoMotionPwcFreeBSD (http://www.lavrsen.dk/foswiki/bin/view/Motion/HowtoMotionPwcFreeBSD)
--without-bktr | Exclude to use bktr subsystem , that usually useful for devices as network cameras | ONLY used in *BSD
--without-v4l | Exclude using v4l (video4linux) subsystem. Makes Motion so it only supports network cameras. | Can be used if you do not need V4L (http://www.lavrsen.dk/foswiki/bin/view/Motion/V4L) support and maybe lack some of the libraries for it.
--with-jpeg-mmx=DIR | Specify the prefix for the install path for jpeg-mmx for optimized jpeg handling (optional). If this is not specified motion will try to find the library /usr/lib/libjpeg-mmx.a /usr/local/lib/libjpeg-mmx.a. | Considered experimental

--with-ffmpeg=DIR

Specify the path for the directory prefix in which the library and headers are installed.
If not specified configure will search in /usr/ and /usr/local/

DIR is the directory PREFIX in which the ffmpeg shared libraries and their headers are installed.
If you install ffmpeg from sources and use the default directories or if ffmpeg is installed as a binary package (RPM or deb) you do not need to specify the directory prefix. Configure will find the libraries automatically. If you installed ffmpeg from sources and specified a different --prefix when building ffmpeg you must use the same value for the DIR ( --with-ffmpeg=DIR).
For more information on FFmpeg see the FFmpeg project home page (http://ffmpeg.sourceforge.net/).
FFmpeg is a package that enables streamed video mpeg signal from your web camera to a browser.
Editor recommends installing ffmpeg from source and in the directory /usr/local/ffmpeg and build ffmpeg with ./configure --enable-shared.
This places libraries in /usr/local/lib and headers in /usr/local/include.
--without-ffmpeg | Do not compile with ffmpeg | Use this if you do not want to compile with ffmpeg. If ffmpeg is not installed you do not need to specify that Motion must build without ffmpeg.
--with-mysql-lib=DIR | Lib directory of MySQL | Normally, configure will scan all possible default installation paths for MySQL libs. When its fail, use this command to tell configure where MySQL libs installation root directory is.
--with-mysql-include=DIR | Include directory with headers for MySQL | Normally, configure will scan all possible default installation paths for MySQL include. When its fail, use this command to tell configure where MySQL include installation directory is. This is the directory with the MySQL header files.
--without-mysql | Do not compile with MySQL support | Use this if you do not want to include MySQL support in the package. This can also be useful if you get compilation errors related to MySQL and you actually do not need the feature anyway.
--without-pgsql | Do not compile with PostgreSQL support | Use this if you do not want to include PostgreSQL support in the package. This can also be useful if you get compilation errors related to PostgreSQL and you actually do not need the feature anyway.
--with-pgsql-include=DIR | Normally, configure will scan all possible default installation paths for pgsql include. When it fails, use this command to tell configure where pgsql include installation root directory is.
--with-pgsql-lib=DIR | Normally, configure will scan all possible default installation paths for pgsql libs. When it fails, use this command to tell configure where pgsql libs installation root directory is.
--without-optimizecpu | Exclude autodetecting platform and cpu type. This will disable the compilation of gcc optimizing code by platform and cpu. | Use this if the optimization causes problems. Typically if you build on some non X386 compatible CPU.
Developers options
--with-developer-flags | Add additional warning flags for the compiler. | This option is for developers only. It produces a flood of warnings that helps the developer to write more robust code. These warnings are normally harmless but can sometimes be a latent defect. For more information about these flags, see CompileWithDeveloperFlags (http://www.lavrsen.dk/foswiki/bin/view/Motion/CompileWithDeveloperFlags)

## Make (http://www.lavrsen.dk/foswiki/bin/view/Motion/MakeInstall)

When you run make, all the C-source files are automatically compiled and linked. Just look out for error messages.

Make uses a file called "Makefile" which is generated by the "configure" script you just ran. If you have special needs you can manually edit this file. Next time you run configure a new Makefile will be generated and your changes are lost.

ALERT! Attention!

If you have run make before, you should run a make clean before running make again. This cleans out all the object files that were generated the previous time you ran make. If you do not run make clean first before you rebuild Motion you may not get the additional feature included. For example: If you built Motion without ffmpeg support and then add it later - and rebuild Motion without running make clean first - the ffmpeg feature does not get compiled into the Motion binary.

First time you build motion run ./configure, make, make install. If you need to build it again (to run with different configure options) run ./configure, make clean, make, make install.

### Make Install

make install simply copies all the nice files that were generated during the compilation/linking that make did.

Makes the directories (if they do not already exist)(path shown are the defaults): /usr/local/bin, usr/local/man/man1, /usr/local/etc, /usr/local/share/doc/motion-3.2.X, and /usr/local/share/doc/examples/motion-3.2.X.

Copies the following files from the base motion directory (assuming the default PREFIX /usr/local was used when running configure - otherwise adjust to the actuals you chose)

- Executable binary "motion" to /usr/local/bin
- Manual page "motion.1" to /usr/local/man/man1
- Document files "CHANGELOG, COPYING, CREDITS, INSTALL, and README to /usr/local/share/doc/motion-3.2.X
- Example configuration files "*.conf" to /usr/local/share/doc/examples/motion-3.2.X
- Configuration file "motion-dist.conf" to /usr/local/etc

Note that the any existing files are overwritten. The default config file motion-dist.conf is named like this so that you do not get your working motion.conf file overwritten when you upgrade Motion.

### Un-install

From the motion base installation directory you simply run make uninstall

And delete the base installation directory in /usr/local and any link pointing to it. If you have forgotten where you installed it or someone else did it for you, simply search for the files and directories starting with motion. If the filenames and the directories match the names described in the "Make Install" section of this document, you can safely delete them.

### Additional Make Options

The make command can be run with several options. make, make install and make uninstall has already been described above.

make clean

deletes all the binary files (object files) and the motion binary generated by make. It also deletes temporary files and any jpg files that motion has saved in the motion source directory. It is very important to always run make clean before you run make if you change the configuration (like adding features such as ffmpeg) and rebuild motion.

make distclean

deletes the files: config.status, config.log, config.cache, Makefile, and motion.spec.

make updateguide

fetches a fresh new copy of this guide and place it in your motion source directory. Note that the pictures are not downloaded.

make dist

performs make clean, make distclean and make updateguide in one single operation.

## Upgrading From Older Version (http://www.lavrsen.dk/foswiki/bin/view/Motion/UpgradingFromOlderVersion)

If you are upgrading from motion 3.0.X or from an older version of 3.1.X you should note that many options have been removed from version 3.1.13 and forward and many new have arrived. You still have most of the old features. The options have been changed for two reasons. New more flexible features and to simplify getting started with Motion. With 3.2.1 the changes are significant. You should also note these major differences.

- The use of thread files has completely changed. Read the section "The Config Files" carefully.
- The mask file format has changed. Read the section about "Mask File"
- Pre_capture feature introduced in 3.1.12
- Advanced filename feature enables very flexible filename definitions (3.1.13)
- onffmpegclose options enables running external scripts when mpeg file is closed (3.1.13)
- despeckle feature improves motion detection and noise immunity (3.1.13)
- Minimum_motion_frames feature prevents short noise events from being saved (3.1.14)
- If you use the database features you need to note that from version 3.1.15 and forward the fields have been redefined. Removed are second, minute, hour, day, month and year. Instead these six have been replaced by a real timestamp field called time_stamp. The relatively new field 'type' has been renamed to 'file_type' to avoid reserved SQL words. A new field 'text_left' has been added which stores the text given by the config option text_left. And last a field called 'camera' has been added which stores the thread number.
- From 3.1.15 the ffmpeg feature now also supports mpeg4 and msmpeg4. The build process of Motion now use ffmpeg libraries as shared libraries. The --with-libavcodec has been replaced by a --with-ffmpeg which only needed to specify if you are installing ffmpeg from sources in a non-standard location. If you have installed ffmpeg from sources already you will need to rebuild by running (from within the ffmpeg source file root) ./configure --enable-shared followed by make and make install. If you had installed ffmpeg from a binary RPM or deb you probably don't have to do anything.
- Rotate feature was introduced in 3.1.15
- Berkeley mpeg feature has been removed in 3.1.18 (use ffmpeg - it is much better)
- Incomplete prediction feature was removed in 3.1.18. (lack of interest in finishing it)
- Smart Mask feature introduced in 3.1.18
- output_normal can now also have the value "first" which means only save first jpg from each event (3.1.18)
- ffmpeg-0.4.9 is now supported. Motion detection mpegs can no longer be saved as mpeg1 (ffmpeg does not support non-standard framerates in 0.4.9) (3.1.18)
- Motion now supports most (not all) mjpeg streaming cameras (3.1.18).
- output_normal can now have values "first" or "best". It is used when you need to present a link to an mpeg movie shown as a single jpeg image. "First" saves the first picture frame in the new event. "Best" saves the picture frame with most motion content (most changed pixels) when the event is over. "on" still saves all motion detection picture frames plus pre and post captured images. With "best" you can set jpeg_filename = "preview" and it gets the same filename as the mpeg file but with extension .jpg. Option "locate" can also take the value "preview" which makes it only draw a rectangel on the jpeg but not on the mpeg movie. (3.2.1)
- The xmlrpc remote control interface is replaced by a much nicer http remote control interface. (3.2.1)
- All the options that calls external programs have been made much more generic. New onxxxx options have been added. Execute, sms and mail have been replaced by the generic on_event_start. (3.2.1)
- New setup mode makes setting all the detection options much easier.
- netcam now also supports proxies (3.2.2) and ftp (3.2.4)
- text on the pictures can be set to double size (3.2.2)
- Tracking with Logitech Sphere/Orbit improved (3.2.4)
- SQL database feature is now fully configurable so you can control which fields you have in the database.
- Many new conversion specifiers have been added which can be used both in filenames, commands, text, and SQL database features (3.2.2-3.2.4)
- Stepper motor tracking feature extended to also include a Y axis (3.2.5)
- ffmpeg_filename has been renamed to movie_filename to prepare for alternative implementation to mpeg files made with ffmpeg (3.2.5)
- New feature: ffmpeg_deinterlace which can de-interlace using the ffmpeg libs (3.2.5)
- New feature: minimum_frame_time which enables Motion to run at frame rates below 2. minimum_gap feature was removed since this was useless and the new minimum_frame_time feature replaces it with much better function. (3.2.7)
- New feature: process_id_file which writes a PID file when started and removes it when stopped (3.2.7)
- V4L2 (http://www.lavrsen.dk/foswiki/bin/view/Motion/V4L2) support with many new supported palettes : V4L2 (http://www.lavrsen.dk/foswiki/bin/view/Motion/V4L2)_PIX_FMT_SBGGR8, V4L2 (http://www.lavrsen.dk/foswiki/bin/view/Motion/V4L2)_PIX_FMT_SN9C10X, V4L2 (http://www.lavrsen.dk/foswiki/bin/view/Motion/V4L2)_PIX_FMT_JPEG, V4L2 (http://www.lavrsen.dk/foswiki/bin/view/Motion/V4L2)_PIX_FMT_UYVY (3.2.8)
- ffmpeg_video_codec allow swf (3.2.8)
- V4L2 (http://www.lavrsen.dk/foswiki/bin/view/Motion/V4L2) fix support for : V4L2 (http://www.lavrsen.dk/foswiki/bin/view/Motion/V4L2)_PIX_FMT_MJPEG (3.2.9)
- ffmpeg_video_codec allow flv and ffv1(3.2.9)
- v4l2_palette: allow to choose preferable palette to be use by motion to capture from those supported by your videodevice.
- netcam_http: setup keep_alive , 1.1 or 1.0 http method to be used by netcam.
- on_camera_lost: Command to be executed when a camera can't be opened or if it is lost.
- AreaDetect (http://www.lavrsen.dk/foswiki/bin/view/Motion/AreaDetect), on_area_detected: Command to be executed by area_detect trigger.
- ConfigOptionNetcamTolerantCheck (http://www.lavrsen.dk/foswiki/bin/view/Motion/ConfigOptionNetcamTolerantCheck) , netcam_tolerant_check less strict jpeg checks for network cameras with a poor/buggy firmware ( 3.2.11 ).

The table below shows the new options in the left column, and obsolete options in the right column. If the there are options on both sides in a row it means that the options in the left column replaced the options in the right column.

New Options (http://www.lavrsen.dk/foswiki/bin/view/Motion/MotionGuideOneLargeDocument;sortcol=0;table=6;up=0) | Obsolete Options (http://www.lavrsen.dk/foswiki/bin/view/Motion/MotionGuideOneLargeDocument;sortcol=1;table=6;up=0)
text_left (3.1.13) text_right (3.1.13) text_changes (3.1.13) | drawtext_user (3.1.13) drawtext_shots (3.1.13) drawtext_changes (3.1.13)
jpeg_filename (3.1.13) ffmpeg_filename (3.1.13) snapshot_filename (3.1.13) timelapse_filename (3.1.13) predict_filename (3.1.13) (predict_filename removed in 3.1.18) | oldlayout (3.1.13) snapshots_overwrite (3.1.13)
snapshot_interval (3.1.13) | snapshots (3.1.13)
| realmotion (3.1.13)
despeckle (3.1.13)
pre_capture (3.1.12)
ffmpeg_timelapse (v. 3.1.14) | ffmpeg_timelaps (renamed v 3.1.14)
ffmpeg_timelapse_mode (3.1.14)
sql_log_image (3.1.14) sql_log_snapshot (3.1.14) sql_log_mpeg (3.1.14) sql_log_timelapse (3.1.14) sql_log_prediction (3.1.14)
minimum_motion_frames (3.1.14)
rotate (3.1.15)
ffmpeg_variable_bitrate (3.1.15) ffmpeg_video_codec (3.1.15)
| berkeley_single_directory (3.1.18) mpeg_encode (3.1.18) mpeg_encode_bin (3.1.18) adjust_rate off (3.1.18) jpg_cleanup (3.1.18)
| predict_filename (3.1.18) predict_enable (3.1.18) predict_threshold (3.1.18) predict_description (3.1.18) sql_log_prediction (3.1.18)
brightness (3.1.18) contrast (3.1.18) saturation (3.1.18) hue (3.1.18)
smart_mask_speed (3.1.18)
output_normal valid values are now "on", "off", "first" (3.1.18) and "best" (3.2.1)
setup_mode (3.2.1) | always_changes (3.2.1)
locate valid values are now "on", "off", "preview" (3.2.1)
jpeg_filename Besides normal path names the value "preview" has speciel meaning together with output_normal = "best" (3.2.1)
control_html_output (3.2.1)
on_event_start (3.2.1) | execute (3.2.1) sms (3.2.1) mail (3.2.1)
on_event_end (3.2.1)
on_motion_detected (3.2.1)
on_picture_save (3.2.1) | onsave (3.2.1)
on_movie_start (3.2.1) on_movie_end (3.2.1) | onmpeg (3.2.1) onffmpegclose (introduced 3.1.13)(renamed to on_movie_end 3.2.1)
netcam_proxy (3.2.2)
text_double (3.2.2)
webcam_motion Feature has been heavily improved so it is actually usefull now (3.2.2).
netcam_url Now also supports fetching single frame jpeg pictures via ftp using ftp:// syntax (3.2.4)
track_step_angle_x (3.2.4) track_step_angle_y (3.2.4) Add better configuration of auto tracking with a Logitech Sphere/Orbit camera.
track_move_wait (3.2.4) track_auto (3.2.4) Adds better configuration of auto tracking feature
sql_query (3.2.4) Adds full flexibility of defining fields when using the SQL database features.
track_maxy (3.2.5) track_motory (3.2.5)
movie_filename (3.2.5) | ffmpeg_filename (3.2.5)
ffmpeg_deinterlace (3.2.5)
minimum_frame_time (3.2.7) | minimum_gap (3.2.7)
process_id_file (3.2.7)
ffmpeg_video_codec allow swf (3.2.8)
ffmpeg_video_codec allow flv and ffv1 (3.2.9)
v4l2_palette (3.2.10) netcam_http (3.2.10) on_camera_lost (3.2.10) area_detect, on_area_detected(3.2.10) ffmpeg_video_codec mov(3.2.10) output_normal center(3.2.10)
| night_compensate (3.2.10) low_cpu (3.2.10)
netcam_tolerant_check (3.2.11)

## Running Motion (http://www.lavrsen.dk/foswiki/bin/view/Motion/RunningMotionConfigFiles)

### Important Definitions

Motion is invoked from the command line. It has no GUI. Everything is controlled from config files. From version 3.2 the command line is only used to define location of config file and a few special runtime modes (setup and non-daemon).

A few important definitions.

- A snapshot is a picture taken at regular intervals independently of any movement in the picture.
- A "motion" image/mpeg shows the pixels that have actually changed during the last frames. These pictures are not very useful for normal presentation to the public but they are quite useful for testing and tuning and making mask files as you can see exactly where motion sees something moving. Motion is shown in greytones. If labelling is enabled the largest area is marked as blue. Smart mask is shown in read.
- A "normal" image is the real image taken by the camera with text overlayed.

### The Config Files

If Motion was invoked with command line option -c pathname Motion will expect the config file to be as specified. When you specify the config file on the command line with -c you can call it anything.

If you do not specify -c or the filename you give Motion does not exist, Motion will search for the configuration file called 'motion.conf' in the following order:

1. Current directory from where motion was invoked
2. Then in a directory called '.motion' in the current users home directory (shell environment variable $HOME). E.g. /home/goofy/.motion/motion.conf
3. The directory defined by the --sysconfdir=DIR when running .configure during installation of Motion (If this option was not defined the default is /usr/local/etc/)

If you have write access to /usr/local/etc then the editor recommends having only one motion.conf file in the default /usr/local/etc/ directory.

Motion has a configuration file in the distribution package called motion-dist.conf. When you run 'make install' this file gets copied to the /usr/local/etc directory.

The configuration file needs to be renamed from motion-dist.conf to motion.conf. The original file is called motion-dist.conf so that your perfectly working motion.conf file does not accidentally get overwritten when you re-install or upgrade to a newer version of Motion.

If you have more than one camera you should not try and invoke Motion more times. Motion is made to work with more than one camera in a very elegant way and the way to do it is to create a number of thread config files. Motion will then create an extra tread of itself for each camera. If you only have one camera you only need the motion.conf file. The minute you have two or more cameras you must have one thread config file per camera besides the motion.conf file.

So if you have for example two cameras you need motion.conf and two thread config files. Total of 3 config files.

An option that is common to all cameras can be placed in motion.conf. (You can also put all parameters in the thread files but that makes a lot of editing when you change a common thing).

An option that is unique to a camera must be defined in each thread file.

It is often seen that people copy the entire motion.conf into the thread config files and change a few options. This works but it not recommended because it is more difficult to maintain and overview. Keep all the common options in motion.conf and the few unique only in the thread config files

The first camera is defined in the first thread file called from motion.conf. The 2nd camera is defined in the 2nd thread file called from motion.conf etc.

Any option defined in motion.conf will be used for all cameras except for the cameras in which the same option is defined in a thread config file.

Motion reads its configuration parameters in the following sequence. If the same parameter exists more than one place the last one read wins.

1. Motion reads the configuration file motion.conf from the beginning of the file going down line by line.
2. If the option "thread" is defined in motion.conf, the thread configuration file(s) is/(are) read.
3. Motion continues reading the rest of the motion.conf file. Any options from here will overrule the same option previously defines in a thread config file.
4. Motion reads the command line option again overruling any previously defined options.

So always call the thread config files in the end of the motion.conf file. If you define options in motion.conf AFTER the thread file calls, the same options in the thread files will never be used. So always put the thread file call at the end of motion.conf.

Nearly all config options can be unique for a specific camera and placed in a thread config file. There are a few options that must be in motion.conf and cannot be in a thread config file: control_authentication (http://www.lavrsen.dk/foswiki/bin/view/Motion/ConfigOptionControlAuthentication), control_html_output (http://www.lavrsen.dk/foswiki/bin/view/Motion/ConfigOptionControlHtmlOutput), control_localhost (http://www.lavrsen.dk/foswiki/bin/view/Motion/ConfigOptionControlLocalhost), control_port (http://www.lavrsen.dk/foswiki/bin/view/Motion/ConfigOptionControlPort), daemon (http://www.lavrsen.dk/foswiki/bin/view/Motion/ConfigOptionDaemon), and thread (http://www.lavrsen.dk/foswiki/bin/view/Motion/ConfigOptionThread).

If motion is built without specific features such as ffmpeg, mysql etc it will ignore the options that belongs to these features. You do not have to remove them or comment them out.

If you run the http control command http://host:port/0/config/writeyes, motion will overwrite motion.conf and all the thread.conf files by autogenerated config files neatly formatted and only with the features included that Motion was built with. If you later re-build Motion with more features or upgrade to a new version, you can use your old config files, run the motion.conf.write command, and you will have new config files with the new options included all set to their default values. This makes upgrading very easy to do.

## Command Line Options (http://www.lavrsen.dk/foswiki/bin/view/Motion/CommandLineOptions)

ALERT! In Motion 3.2.1 and forward most command line options have been removed and replaced them by an option to specify location to motion.conf and a few options related to setting up motion. There are now only few command line options left and they are basically all new.

SYNOPSIS

motion [ -hns ] [ -c config file path ] [ -d level ]  [ -p process_id_file ]

Option (http://www.lavrsen.dk/foswiki/bin/view/Motion/MotionGuideOneLargeDocument;sortcol=0;table=7;up=0) | Description (http://www.lavrsen.dk/foswiki/bin/view/Motion/MotionGuideOneLargeDocument;sortcol=1;table=7;up=0) | Editors comment (http://www.lavrsen.dk/foswiki/bin/view/Motion/MotionGuideOneLargeDocument;sortcol=2;table=7;up=0)
-n | Run in non-daemon mode. | Instead of running Motion in the background Motion runs in the terminal window writing messages when things happen. If you have problems getting Motion to start or work, run Motion in this mode to get more messages that can help you solve the problem.
-s | Run in setup mode. | Also forces non-daemon mode
-c config file path | Full path and filename of config file. | E.g. /home/kurt/motion.conf. Default is /usr/local/etc unless specified differently when building Motion. Many RPMs and debian packages will most likely use /etc or /etc/motion as default
-h | Show help screen.
-d level | Debugging mode | This mode is used for developers to enable debug messages. Normal users will not need to use this mode unless a developer request to get additional information in the attempt to resolve a bug. Mainly the netcam code has debugging features. The level defines how much debugging info you get. A high number displays all debugging.
-p process_id_file | Full path of process ID file | Full path and filename of process id file (PID file). This is optional. If none is given as command line option or in motion.conf (process_id_file) Motion will not create a PID file.

## Config File Options (http://www.lavrsen.dk/foswiki/bin/view/Motion/ConfigFileOptions)

These are the options that can be used in the config file.

All number values are integer numbers (no decimals allowed). Boolean options can be on or off.

Some configuration options are only used if Motion is built on a system that has the matching software libraries installed (MySQL, PostgreSQL and FFMPEG).

MySQL

- mysql_db, mysql_host, mysql_user, mysql_password

PostgreSQL

- pgsql_db, pgsql_host, pgsql_user, pgsql_password, pgsql_port

FFMPEG (libavcodec)

- ffmpeg_cap_new, ffmpeg_cap_motion, ffmpeg_filename, ffmpeg_timelapse, ffmpeg_timelapse_mode, ffmpeg_bps, ffmpeg_variable_bitrate, ffmpeg_video_codec

### Options in Alphabetical Order.

The table below lists all the Motion options in alphabetical order. Click on the option name to see a longer description of each.

Option (http://www.lavrsen.dk/foswiki/bin/view/Motion/MotionGuideOneLargeDocument;sortcol=0;table=8;up=0) | Range/Values Default (http://www.lavrsen.dk/foswiki/bin/view/Motion/MotionGuideOneLargeDocument;sortcol=1;table=8;up=0) | Description (http://www.lavrsen.dk/foswiki/bin/view/Motion/MotionGuideOneLargeDocument;sortcol=2;table=8;up=0)
area_detect (http://www.lavrsen.dk/foswiki/bin/view/Motion/ConfigOptionAreaDetect) | Values: 1 - 999999999 Default: Not defined | Detect motion center in predefined areas. A script (on_area_detected) is started immediately when motion center is detected in one of the given areas, but only once during an event even if there is motion in a different configured area.
auto_brightness (http://www.lavrsen.dk/foswiki/bin/view/Motion/ConfigOptionAutoBrightness) | Values: on, off Default: off | Let motion regulate the brightness of a video device. Only recommended for cameras without auto brightness
brightness (http://www.lavrsen.dk/foswiki/bin/view/Motion/ConfigOptionBrightness) | Values: 0 - 255 Default: 0 (disabled) | The brightness level for the video device.
contrast (http://www.lavrsen.dk/foswiki/bin/view/Motion/ConfigOptionContrast) | Values: 0 - 255 Default: 0 (disabled) | The contrast level for the video device.
control_authentication (http://www.lavrsen.dk/foswiki/bin/view/Motion/ConfigOptionControlAuthentication) | Values: Max 4096 characters Default: Not defined | To protect HTTP Control by username and password, use this option for HTTP 1.1 Basic authentication. The string is specified as username:password. Do not specify this option for no authentication. This option must be placed in motion.conf and not in a thread config file.
control_html_output (http://www.lavrsen.dk/foswiki/bin/view/Motion/ConfigOptionControlHtmlOutput) | Values: on, off Default: on | Enable HTML in the answer sent back to a browser connecting to the control_port. This option must be placed in motion.conf and not in a thread config file.
control_localhost (http://www.lavrsen.dk/foswiki/bin/view/Motion/ConfigOptionControlLocalhost) | Values: on, off Default: on | Limits the http (html) control to the localhost. This option must be placed in motion.conf and not in a thread config file.
control_port (http://www.lavrsen.dk/foswiki/bin/view/Motion/ConfigOptionControlPort) | Values: 0 - 65535 Default: 0 (disabled) | Sets the port number for the http (html using browser) based remote control. This option must be placed in motion.conf and not in a thread config file.
daemon (http://www.lavrsen.dk/foswiki/bin/view/Motion/ConfigOptionDaemon) | Values: on, off Default: off | Start in daemon (background) mode and release terminal. This option must be placed in motion.conf and not in a thread config file.
despeckle (http://www.lavrsen.dk/foswiki/bin/view/Motion/ConfigOptionDespeckle) | Values: EedDl Default: Not defined | Despeckle motion image using combinations of (E/e)rode or (D/d)ilate. And ending with optional (l)abeling.
ffmpeg_bps (http://www.lavrsen.dk/foswiki/bin/view/Motion/ConfigOptionFfmpegBps) | Values: 0 - 9999999 Default: 400000 | Bitrate of mpegs produced by ffmpeg. Bitrate is bits per second. Default: 400000 (400kbps). Higher value mans better quality and larger files. Option requires that ffmpeg libraries are installed.
ffmpeg_cap_motion (http://www.lavrsen.dk/foswiki/bin/view/Motion/ConfigOptionFfmpegCapMotion) | Values: on, off Default: off | Use ffmpeg libraries to encode motion type mpeg movies where you only see the pixels that changes.
ffmpeg_cap_new (http://www.lavrsen.dk/foswiki/bin/view/Motion/ConfigOptionFfmpegCapNew) | Values: on, off Default: off | Use ffmpeg libraries to encode mpeg movies in realtime.
ffmpeg_deinterlace (http://www.lavrsen.dk/foswiki/bin/view/Motion/ConfigOptionFfmpegDeinterlace) | Values: on, off Default: off | Use ffmpeg to deinterlace video. Necessary if you use an analog camera and see horizontal combing on moving objects in video or pictures.
ffmpeg_filename (now called movie_filename) (http://www.lavrsen.dk/foswiki/bin/view/Motion/ConfigOptionFfmpegFilename) | Values: Max 4095 characters Default: %v-%Y%m%d%H%M%S | File path for motion triggered ffmpeg movies (mpeg) relative to target_dir. This option was renamed to movie_filename in 3.2.5 to enable better integration of alternative movie libraries to the current ffmpeg solution.
ffmpeg_timelapse (http://www.lavrsen.dk/foswiki/bin/view/Motion/ConfigOptionFfmpegTimelapse) | Values: 0 - 2147483647 Default: 0 (disabled) | Create a timelapse movie saving a picture frame at the interval in seconds set by this parameter. Set it to 0 if not used.
ffmpeg_timelapse_mode (http://www.lavrsen.dk/foswiki/bin/view/Motion/ConfigOptionFfmpegTimelapseMode) | Values: hourly, daily, weekly-sunday, weekly-monday, monthly, manual Default: daily | The file rollover mode of the timelapse video.
ffmpeg_variable_bitrate (http://www.lavrsen.dk/foswiki/bin/view/Motion/ConfigOptionFfmpegVariableBitrate) | Values: 0, 2 - 31 Default: 0 (disabled) | Enables and defines variable bitrate for the ffmpeg encoder. ffmpeg_bps is ignored if variable bitrate is enabled. Valid values: 0 (default) = fixed bitrate defined by ffmpeg_bps, or the range 2 - 31 where 2 means best quality and 31 is worst.
ffmpeg_video_codec (http://www.lavrsen.dk/foswiki/bin/view/Motion/ConfigOptionFfmpegVideoCodec) | Values: mpeg1 (ffmpeg-0.4.8 only), mpeg4, msmpeg4, swf, flv, ffv1, mov Default: mpeg4 | Codec to be used by ffmpeg for the video compression. Timelapse mpegs are always made in mpeg1 format independent from this option.
framerate (http://www.lavrsen.dk/foswiki/bin/view/Motion/ConfigOptionFramerate) | Values: 2 - 100 Default: 100 (no limit) | Maximum number of frames to be captured from the camera per second.
frequency (http://www.lavrsen.dk/foswiki/bin/view/Motion/ConfigOptionFrequency) | Values: 0 - 999999 Default: 0 (Not set) | The frequency to set the tuner to (kHz). Valid range: per tuner spec, default: 0 (Don't set it)
gap (http://www.lavrsen.dk/foswiki/bin/view/Motion/ConfigOptionGap) | Values: 0 - 2147483647 Default: 60 | Gap is the seconds of no motion detection that triggers the end of an event. An event is defined as a series of motion images taken within a short timeframe.
height (http://www.lavrsen.dk/foswiki/bin/view/Motion/ConfigOptionHeight) | Values: Device Dependent Default: 288 | The height of each frame in pixels.
hue (http://www.lavrsen.dk/foswiki/bin/view/Motion/ConfigOptionHue) | Values: 0 - 255 Default: 0 (disabled) | The hue level for the video device.
input (http://www.lavrsen.dk/foswiki/bin/view/Motion/ConfigOptionInput) | Values: 0 - 7, 8 = disabled Default: 8 (disabled) | Input channel to use expressed as an integer number starting from 0. Should normally be set to 1 for video/TV cards, and 8 for USB cameras.
jpeg_filename (http://www.lavrsen.dk/foswiki/bin/view/Motion/ConfigOptionJpegFilename) | Values: Max 4095 characters Default: %v-%Y%m%d%H%M%S-%q | File path for motion triggered images (jpeg or ppm) relative to target_dir. Value 'preview' makes a jpeg filename with the same name body as the associated saved mpeg movie file.
lightswitch (http://www.lavrsen.dk/foswiki/bin/view/Motion/ConfigOptionLightswitch) | Values: 0 - 100 Default: 0 (disabled) | Ignore sudden massive light intensity changes given as a percentage of the picture area that changed intensity.
locate (http://www.lavrsen.dk/foswiki/bin/view/Motion/ConfigOptionLocate) | Values: on, off, preview Default: off | Locate and draw a box around the moving object. Value 'preview' makes Motion only draw a box on a saved preview jpeg image and not on the saved mpeg movie.
mask_file (http://www.lavrsen.dk/foswiki/bin/view/Motion/ConfigOptionMaskFile) | Values: Max 4095 characters Default: Not defined | PGM file to use as a sensitivity mask. This picture MUST have the same width and height as the frames being captured and be in binary format.
max_mpeg_time (http://www.lavrsen.dk/foswiki/bin/view/Motion/ConfigOptionMaxMpegTime) | Values: 0 (infinite) - 2147483647 Default: 3600 | The maximum length of an mpeg movie in seconds. Set this to zero for unlimited length.
minimum_frame_time (http://www.lavrsen.dk/foswiki/bin/view/Motion/ConfigOptionMinimumFrameTime) | Values: 0 - 2147483647 Default: 0 | Minimum time in seconds between the capturing picture frames from the camera. Default: 0 = disabled - the capture rate is given by the camera framerate.
minimum_motion_frames (http://www.lavrsen.dk/foswiki/bin/view/Motion/ConfigOptionMinimumMotionFrames) | Values: 1 - 1000s Default: 1 | Picture frames must contain motion at least the specified number of frames in a row before they are detected as true motion. At the default of 1, all motion is detected. Valid range is 1 to thousands, but it is recommended to keep it within 1-5.
motion_video_pipe (http://www.lavrsen.dk/foswiki/bin/view/Motion/ConfigOptionMotionVideoPipe) | Values: Max 4095 characters Default: Not defined | The video4linux video loopback input device for motion images. If a particular pipe is to be used then use the device filename of this pipe, if a dash '-' is given motion will use /proc/video/vloopback/vloopbacks to locate a free pipe. Default: not set
movie_filename (http://www.lavrsen.dk/foswiki/bin/view/Motion/ConfigOptionMovieFilename) | Values: Max 4095 characters Default: %v-%Y%m%d%H%M%S | File path for motion triggered ffmpeg movies (mpeg) relative to target_dir. This was previously called ffmpeg_filename.
mysql_db (http://www.lavrsen.dk/foswiki/bin/view/Motion/ConfigOptionMysqlDb) | Values: Max 4095 characters Default: Not defined | Name of the MySQL database.
mysql_host (http://www.lavrsen.dk/foswiki/bin/view/Motion/ConfigOptionMysqlHost) | Values: Max 4095 characters Default: localhost | IP address or domain name for the MySQL server. Use "localhost" if motion and MySQL runs on the same server.
mysql_password (http://www.lavrsen.dk/foswiki/bin/view/Motion/ConfigOptionMysqlPassword) | Values: Max 4095 characters Default: Not defined | The MySQL password.
mysql_user (http://www.lavrsen.dk/foswiki/bin/view/Motion/ConfigOptionMysqlUser) | Values: Max 4095 characters Default: Not defined | The MySQL user name.
netcam_http (http://www.lavrsen.dk/foswiki/bin/view/Motion/ConfigOptionNetcamHttp) | Values: 1.0, keep_alive, 1.1 Default: 1.0 | The setting for keep-alive of network socket, should improve performance on compatible net cameras. ( new in 3.2.10 )
netcam_proxy (http://www.lavrsen.dk/foswiki/bin/view/Motion/ConfigOptionNetcamProxy) | Values: Max 4095 characters Default: Not defined | URL to use for a netcam proxy server, if required. The syntax is http://myproxy:portnumber
netcam_tolerant_check (http://www.lavrsen.dk/foswiki/bin/view/Motion/ConfigOptionNetcamTolerantCheck) | Values: on, off Default: off | Set less strict jpeg checks for network cameras with a poor/buggy firmware.
netcam_url (http://www.lavrsen.dk/foswiki/bin/view/Motion/ConfigOptionNetcamUrl) | Values: Max 4095 characters Default: Not defined | Specify an url to a downloadable jpeg file or raw mjpeg stream to use as input device. Such as an AXIS 2100 network camera.
netcam_userpass (http://www.lavrsen.dk/foswiki/bin/view/Motion/ConfigOptionNetcamUserpass) | Values: Max 4095 characters Default: Not defined | For network cameras protected by username and password, use this option for HTTP 1.1 Basic authentication. The string is specified as username:password. Do not specify this option for no authentication.
noise_level (http://www.lavrsen.dk/foswiki/bin/view/Motion/ConfigOptionNoiseLevel) | Values: 1 - 255 Default: 32 | The noise level is used as a threshold for distinguishing between noise and motion.
noise_tune (http://www.lavrsen.dk/foswiki/bin/view/Motion/ConfigOptionNoiseTune) | Values: on, off Default: on | Activates the automatic tuning of noise level.
norm (http://www.lavrsen.dk/foswiki/bin/view/Motion/ConfigOptionNorm) | Values: 0 (PAL), 1 (NTSC), 2 (SECAM), 3 (PAL NC no colour) Default: 0 (PAL) | Select the norm of the video device. Values: 0 (PAL), 1 (NTSC), 2 (SECAM), 3 (PAL NC no colour). Default: 0 (PAL)
on_area_detected (http://www.lavrsen.dk/foswiki/bin/view/Motion/ConfigOptionOnAreaDetected) | Values: Max 4095 characters Default: Not defined | Command to be executed when motion in a predefined area is detected. Check option area_detect.
on_camera_lost (http://www.lavrsen.dk/foswiki/bin/view/Motion/ConfigOptionOnCameraLost) | Values: Max 4095 characters Default: Not defined | Command to be executed when a camera can't be opened or if it is lost. You can use Conversion Specifiers (http://www.lavrsen.dk/foswiki/bin/view/Motion/ConversionSpecifiers) and spaces as part of the command. Use %f for passing filename (with full path) to the command. (new in 3.2.10)
on_event_end (http://www.lavrsen.dk/foswiki/bin/view/Motion/ConfigOptionOnEventEnd) | Values: Max 4095 characters Default: Not defined | Command to be executed when an event ends after a period of no motion. The period of no motion is defined by option gap. You can use Conversion Specifiers (http://www.lavrsen.dk/foswiki/bin/view/Motion/ConversionSpecifiers) and spaces as part of the command.
on_event_start (http://www.lavrsen.dk/foswiki/bin/view/Motion/ConfigOptionOnEventStart) | Values: Max 4095 characters Default: Not defined | Command to be executed when an event starts. An event starts at first motion detected after a period of no motion defined by gap. You can use ConversionSpecifiers (http://www.lavrsen.dk/foswiki/bin/view/Motion/ConversionSpecifiers) and spaces as part of the command.
on_motion_detected (http://www.lavrsen.dk/foswiki/bin/view/Motion/ConfigOptionOnMotionDetected) | Values: Max 4095 characters Default: Not defined | Command to be executed when a motion frame is detected. You can use Conversion Specifiers (http://www.lavrsen.dk/foswiki/bin/view/Motion/ConversionSpecifiers) and spaces as part of the command.
on_movie_end (http://www.lavrsen.dk/foswiki/bin/view/Motion/ConfigOptionOnMovieEnd) | Values: Max 4095 characters Default: Not defined | Command to be executed when an ffmpeg movie is closed at the end of an event. You can use Conversion Specifiers (http://www.lavrsen.dk/foswiki/bin/view/Motion/ConversionSpecifiers) and spaces as part of the command. Use %f for passing filename (with full path) to the command.
on_movie_start (http://www.lavrsen.dk/foswiki/bin/view/Motion/ConfigOptionOnMovieStart) | Values: Max 4095 characters Default: Not defined | Command to be executed when an mpeg movie is created. You can use Conversion Specifiers (http://www.lavrsen.dk/foswiki/bin/view/Motion/ConversionSpecifiers) and spaces as part of the command. Use %f for passing filename (with full path) to the command.
on_picture_save (http://www.lavrsen.dk/foswiki/bin/view/Motion/ConfigOptionOnPictureSave) | Values: Max 4095 characters Default: Not defined | Command to be executed when an image is saved. You can use Conversion Specifiers (http://www.lavrsen.dk/foswiki/bin/view/Motion/ConversionSpecifiers) and spaces as part of the command. Use %f for passing filename (with full path) to the command.
output_all (http://www.lavrsen.dk/foswiki/bin/view/Motion/ConfigOptionOutputAll) | Values: on, off Default: off | Picture are saved continuously as if motion was detected all the time.
output_motion (http://www.lavrsen.dk/foswiki/bin/view/Motion/ConfigOptionOutputMotion) | Values: on, off Default: off | Output pictures with only the moving object. This feature generates the special motion type movies where you only see the pixels that changes as a graytone image. If labelling is enabled you see the largest area in blue. Smartmask is shown in red.
output_normal (http://www.lavrsen.dk/foswiki/bin/view/Motion/ConfigOptionOutputNormal) | Values: on, off, first, best, center (since 3.2.10) Default: on | Normal image is an image that is stored when motion is detected. It is the same image that was taken by the camera. I.e. not a motion image like defined by output_motion. Default is that normal images are stored.
pgsql_db (http://www.lavrsen.dk/foswiki/bin/view/Motion/ConfigOptionPgsqlDb) | Values: Max 4095 characters Default: Not defined | Name of the PostgreSQL database.
pgsql_host (http://www.lavrsen.dk/foswiki/bin/view/Motion/ConfigOptionPgsqlHost) | Values: Max 4095 characters Default: localhost | IP address or domain name for the PostgreSQL server. Use "localhost" if motion and PostgreSQL runs on the same server.
pgsql_password (http://www.lavrsen.dk/foswiki/bin/view/Motion/ConfigOptionPgsqlPassword) | Values: Max 4095 characters Default: Not defined | The PostgreSQL password.
pgsql_port (http://www.lavrsen.dk/foswiki/bin/view/Motion/ConfigOptionPgsqlPort) | Values: 0 - 65535 Default: 5432 | The PostgreSQL server port number.
pgsql_user (http://www.lavrsen.dk/foswiki/bin/view/Motion/ConfigOptionPgsqlUser) | Values: Max 4095 characters Default: Not defined | The PostgreSQL user name.
post_capture (http://www.lavrsen.dk/foswiki/bin/view/Motion/ConfigOptionPostCapture) | Values: 0 - 2147483647 Default: 0 (disabled) | Specifies the number of frames to be captured after motion has been detected.
ppm (http://www.lavrsen.dk/foswiki/bin/view/Motion/ConfigOptionPpm) | Values: on, off Default: off | Output ppm images instead of jpeg. This uses less CPU time, but causes a LOT of hard disk I/O, and it is generally slower than jpeg.
pre_capture (http://www.lavrsen.dk/foswiki/bin/view/Motion/ConfigOptionPreCapture) | Values: 0 - 100s Default: 0 (disabled) | Specifies the number of previous frames to be outputted at motion detection. Recommended range: 0 to 5, default=0. Do not use large values! Large values will cause Motion to skip video frames and cause unsmooth mpegs. To smooth mpegs use larger values of post_capture instead.
process_id_file (http://www.lavrsen.dk/foswiki/bin/view/Motion/ConfigOptionProcessIdFile) | Values: Max 4095 characters Default: Not defined | File to store the process ID, also called pid file. Recommended value when used: /var/run/motion.pid
quality (http://www.lavrsen.dk/foswiki/bin/view/Motion/ConfigOptionQuality) | Values: 1 - 100 Default: 75 | The quality for the jpeg images in percent.
quiet (http://www.lavrsen.dk/foswiki/bin/view/Motion/ConfigOptionQuiet) | Values: on, off Default: off | Be quiet, don't output beeps when detecting motion.
rotate (http://www.lavrsen.dk/foswiki/bin/view/Motion/ConfigOptionRotate) | Values: 0, 90, 180, 270 Default: 0 (not rotated) | Rotate image the given number of degrees. The rotation affects all saved images as well as mpeg movies.
roundrobin_frames (http://www.lavrsen.dk/foswiki/bin/view/Motion/ConfigOptionRoundrobinFrames) | Values: 1 - 2147483647 Default: 1 | Specifies the number of frames to capture before switching inputs, this way also slow switching (e.g. every second) is possible.
roundrobin_skip (http://www.lavrsen.dk/foswiki/bin/view/Motion/ConfigOptionRoundrobinSkip) | Values: 1 - 2147483647 Default: 1 | Specifies the number of frames to skip after a switch. (1 if you are feeling lucky, 2 if you want to be safe).
saturation (http://www.lavrsen.dk/foswiki/bin/view/Motion/ConfigOptionSaturation) | Values: 0 - 255 Default: 0 (disabled) | The colour saturation level for the video device.
setup_mode (http://www.lavrsen.dk/foswiki/bin/view/Motion/ConfigOptionSetupMode) | Values: on, off Default: off | Run Motion in setup mode.
smart_mask_speed (http://www.lavrsen.dk/foswiki/bin/view/Motion/ConfigOptionSmartMaskSpeed) | Values: 0 - 10 Default: 0 (disabled) | Slugginess of the smart mask. Default is 0 = DISABLED. 1 is slow, 10 is fast.
snapshot_filename (http://www.lavrsen.dk/foswiki/bin/view/Motion/ConfigOptionSnapshotFilename) | Values: Max 4095 characters Default: %v-%Y%m%d%H%M%S-snapshot | File path for snapshots (jpeg or ppm) relative to target_dir.
snapshot_interval (http://www.lavrsen.dk/foswiki/bin/view/Motion/ConfigOptionSnapshotInterval) | Values: 0 - 2147483647 Default: 0 (disabled) | Make automated snapshots every 'snapshot_interval' seconds.
sql_log_image (http://www.lavrsen.dk/foswiki/bin/view/Motion/ConfigOptionSqlLogImage) | Values: on, off Default: on | Log to the database when creating motion triggered image file.
sql_log_mpeg (http://www.lavrsen.dk/foswiki/bin/view/Motion/ConfigOptionSqlLogMpeg) | Values: on, off Default: off | Log to the database when creating motion triggered mpeg file.
sql_log_snapshot (http://www.lavrsen.dk/foswiki/bin/view/Motion/ConfigOptionSqlLogSnapshot) | Values: on, off Default: on | Log to the database when creating a snapshot image file.
sql_log_timelapse (http://www.lavrsen.dk/foswiki/bin/view/Motion/ConfigOptionSqlLogTimelapse) | Values: on, off Default: off | Log to the database when creating timelapse mpeg file
sql_query (http://www.lavrsen.dk/foswiki/bin/view/Motion/ConfigOptionSqlQuery) | Values: Max 4095 characters Default: insert into security(camera, filename, frame, file_type, time_stamp, text_event) values('%t', '%f', '%q', '%n', '%Y-%m-%d %T', '%C') | SQL query string that is sent to the database. The values for each field are given by using convertion specifiers (http://www.lavrsen.dk/foswiki/bin/view/Motion/ConversionSpecifiers)
switchfilter (http://www.lavrsen.dk/foswiki/bin/view/Motion/ConfigOptionSwitchfilter) | Values: on, off Default: off | Turns the switch filter on or off. The filter can distinguish between most switching noise and real motion. With this you can even set roundrobin_skip to 1 without generating much false detection.
target_dir (http://www.lavrsen.dk/foswiki/bin/view/Motion/ConfigOptionTargetDir) | Values: Max 4095 characters Default: Not defined = current working directory | Target directory for picture and movie files.
text_changes (http://www.lavrsen.dk/foswiki/bin/view/Motion/ConfigOptionTextChanges) | Values: on, off Default: off | Turns the text showing changed pixels on/off.
text_double (http://www.lavrsen.dk/foswiki/bin/view/Motion/ConfigOptionTextDouble) | Values: on, off Default: off | Draw characters at twice normal size on images.
text_event (http://www.lavrsen.dk/foswiki/bin/view/Motion/ConfigOptionTextEvent) | Values: Max 4095 characters Default: %Y%m%d%H%M%S | This option defines the value of the speciel event conversion specifier %C. You can use any conversion specifier in this option except %C. Date and time values are from the timestamp of the first image in the current event.
text_left (http://www.lavrsen.dk/foswiki/bin/view/Motion/ConfigOptionTextLeft) | Values: Max 4095 characters Default: Not defined | User defined text overlayed on each in the lower left corner. Use A-Z, a-z, 0-9, " / ( ) @ ~ # < > , . : - + _ \n and vertical bar and conversion specifiers (http://www.lavrsen.dk/foswiki/bin/view/Motion/ConversionSpecifiers) (codes starting by a %).
text_right (http://www.lavrsen.dk/foswiki/bin/view/Motion/ConfigOptionTextRight) | Values: Max 4095 characters Default: %Y-%m-%d\n%T | User defined text overlayed on each in the lower right corner. Use A-Z, a-z, 0-9, " / ( ) @ ~ # < > , . : - + _ \n and vertical bar and conversion specifiers (http://www.lavrsen.dk/foswiki/bin/view/Motion/ConversionSpecifiers) (codes starting by a %). Default: %Y-%m-%d\n%T = date in ISO format and time in 24 hour clock
thread (http://www.lavrsen.dk/foswiki/bin/view/Motion/ConfigOptionThread) | Values: Max 4095 characters Default: Not defined | Specifies full path and filename for a thread config file. Each camera needs a thread config file containing the options that are unique to the camera. If you only have one camera you do not need thread config files. If you have two or more cameras you need one thread config file for each camera in addition to motion.conf. This option must be placed in motion.conf and not in a thread config file.
threshold (http://www.lavrsen.dk/foswiki/bin/view/Motion/ConfigOptionThreshold) | Values: 1 - 2147483647 Default: 1500 | Threshold for declaring motion. The threshold is the number of changed pixels counted after noise filtering, masking, despeckle, and labelling.
threshold_tune (http://www.lavrsen.dk/foswiki/bin/view/Motion/ConfigOptionThresholdTune) | Values: on, off Default: off | Activates the automatic tuning of threshold level. ( It's broken )
timelapse_filename (http://www.lavrsen.dk/foswiki/bin/view/Motion/ConfigOptionTimelapseFilename) | Values: Max 4095 characters Default: %v-%Y%m%d-timelapse | File path for timelapse mpegs relative to target_dir (ffmpeg only).
track_auto (http://www.lavrsen.dk/foswiki/bin/view/Motion/ConfigOptionTrackAuto) | Values: on, off Default: off | Enable auto tracking
track_iomojo_id (http://www.lavrsen.dk/foswiki/bin/view/Motion/ConfigOptionTrackIomojoId) | Values: 0 - 65535 Default: 0 | Use this option if you have an iomojo smilecam connected to the serial port instead of a general stepper motor controller.
track_maxx (http://www.lavrsen.dk/foswiki/bin/view/Motion/ConfigOptionTrackMaxx) | Values: 0 - 65535 Default: 0 | The maximum position for servo x.
track_maxy (http://www.lavrsen.dk/foswiki/bin/view/Motion/ConfigOptionTrackMaxy) | Values: 0 - 65535 Default: 0 | The maximum position for servo y.
track_motorx (http://www.lavrsen.dk/foswiki/bin/view/Motion/ConfigOptionTrackMotorx) | Values: 0 - 65535 Default: 0 | The motor number that is used for controlling the x-axis.
track_motory (http://www.lavrsen.dk/foswiki/bin/view/Motion/ConfigOptionTrackMotory) | Values: 0 - 65535 Default: 0 | The motor number that is used for controlling the y-axis.
track_move_wait (http://www.lavrsen.dk/foswiki/bin/view/Motion/ConfigOptionTrackMoveWait) | Values: 0 - 65535 Default: 10 | Delay during which tracking is disabled after auto tracking has moved the camera. Delay is defined as number of picture frames.
track_port (http://www.lavrsen.dk/foswiki/bin/view/Motion/ConfigOptionTrackPort) | Values: Max 4095 characters Default: Not defined | This is the device name of the serial port to which the stepper motor interface is connected.
track_speed (http://www.lavrsen.dk/foswiki/bin/view/Motion/ConfigOptionTrackSpeed) | Values: 0 - 255 Default: 255 | Speed to set the motor to.
track_step_angle_x (http://www.lavrsen.dk/foswiki/bin/view/Motion/ConfigOptionTrackStepAngleX) | Values: 0-90 Default: 10 | Angle in degrees the camera moves per step on the X-axis with auto tracking. Currently only used with pwc type cameras.
track_step_angle_y (http://www.lavrsen.dk/foswiki/bin/view/Motion/ConfigOptionTrackStepAngleY) | Values: 0-40 Default: 10 | Angle in degrees the camera moves per step on the Y-axis with auto tracking. Currently only used with pwc type cameras.
track_stepsize (http://www.lavrsen.dk/foswiki/bin/view/Motion/ConfigOptionTrackStepsize) | Values: 0 - 255 Default: 40 | Number of steps to make.
track_type (http://www.lavrsen.dk/foswiki/bin/view/Motion/ConfigOptionTrackType) | Values: 0 (none), 1 (stepper), 2 (iomojo), 3 (pwc), 4 (generic), 5 (uvcvideo) Default: 0 (None) | Type of tracker.
tunerdevice (http://www.lavrsen.dk/foswiki/bin/view/Motion/ConfigOptionTunerdevice) | Values: Max 4095 characters Default: /dev/tuner0 | The tuner device used for controlling the tuner in a tuner card. This option is only used when Motion is compiled for FreeBSD (http://www.lavrsen.dk/foswiki/bin/view/Motion/FreeBSD).
v4l2_palette (http://www.lavrsen.dk/foswiki/bin/view/Motion/ConfigOptionV4L2Palette) | Values: 0 - 8 Default: 8 | Allow to choose preferable palette to be use by motion to capture from those supported by your videodevice. ( new in 3.2.10 )
video_pipe (http://www.lavrsen.dk/foswiki/bin/view/Motion/ConfigOptionVideoPipe) | Values: Max 4095 characters Default: Not defined | The video4linux video loopback input device for normal images. If a particular pipe is to be used then use the device filename of this pipe. If a dash '-' is given motion will use /proc/video/vloopback/vloopbacks to locate a free pipe.
videodevice (http://www.lavrsen.dk/foswiki/bin/view/Motion/ConfigOptionVideodevice) | Values: Max 4095 characters Default: /dev/video0 (FreeBSD (http://www.lavrsen.dk/foswiki/bin/view/Motion/FreeBSD): /dev/bktr0) | The video device to be used for capturing. Default for Linux is /dev/video0. for FreeBSD (http://www.lavrsen.dk/foswiki/bin/view/Motion/FreeBSD) the default is /dev/bktr0.
webcam_limit (http://www.lavrsen.dk/foswiki/bin/view/Motion/ConfigOptionWebcamLimit) | Values: 0 - 2147483647 Default: 0 (unlimited) | Limit the number of frames to number frames. After 'webcam_limit' number of frames the connection will be closed by motion. The value 0 means unlimited.
webcam_localhost (http://www.lavrsen.dk/foswiki/bin/view/Motion/ConfigOptionWebcamLocalhost) | Values: on, off Default: on | Limits the access to the webcam to the localhost.
webcam_maxrate (http://www.lavrsen.dk/foswiki/bin/view/Motion/ConfigOptionWebcamMaxrate) | Values: 1 - 100 Default: 1 | Limit the framerate of the webcam in frames per second. Default is 1. Set the value to 100 for practically unlimited.
webcam_motion (http://www.lavrsen.dk/foswiki/bin/view/Motion/ConfigOptionWebcamMotion) | Values: on, off Default: off | If set to 'on' Motion sends slows down the webcam stream to 1 picture per second when no motion is detected. When motion is detected the stream runs as defined by webcam_maxrate. When 'off' the webcam stream always runs as defined by webcam_maxrate.
webcam_port (http://www.lavrsen.dk/foswiki/bin/view/Motion/ConfigOptionWebcamPort) | Values: 0 - 65535 Default: 0 (disabled) | TCP port on which motion will listen for incoming connects with its webcam server.
webcam_quality (http://www.lavrsen.dk/foswiki/bin/view/Motion/ConfigOptionWebcamQuality) | Values: 1 - 100 Default: 50 | Quality setting in percent for the mjpeg picture frames transferred over the webcam connection. Keep it low to restrict needed bandwidth.
width (http://www.lavrsen.dk/foswiki/bin/view/Motion/ConfigOptionWidth) | Values: Device Dependent Default: 352 | The width in pixels of each frame. Valid range is camera dependent.

### Obsolete Options

Option (http://www.lavrsen.dk/foswiki/bin/view/Motion/MotionGuideOneLargeDocument;sortcol=0;table=9;up=0) | Range/Values Default (http://www.lavrsen.dk/foswiki/bin/view/Motion/MotionGuideOneLargeDocument;sortcol=1;table=9;up=0) | Description (http://www.lavrsen.dk/foswiki/bin/view/Motion/MotionGuideOneLargeDocument;sortcol=2;table=9;up=0)
low_cpu (http://www.lavrsen.dk/foswiki/bin/view/Motion/ConfigOptionLowCpu) | Values: 0 - 100 Default: 0 (disabled) | When this option is not zero motion will be in a low cpu mode while not detecting motion. In low cpu mode Motion reduces the framerate to the value given for this option. Value zero means disabled. ( DEPRECATED )
minimum_gap (http://www.lavrsen.dk/foswiki/bin/view/Motion/ConfigOptionMinimumGap) | Values: 0 - 2147483647 Default: 0 (no minimum) | The minimum time between two shots in seconds. ( DEPRECATED )
night_compensate (http://www.lavrsen.dk/foswiki/bin/view/Motion/ConfigOptionNightCompensate) | Values: on, off Default: off | When this option is set the noise threshold will be lowered if the picture is dark. This will improve the sensitivity in dark places. However it might also increase the number of false alarms since most cameras also increase light sensitivity with their AGC (Automatic Gain Control) and this will increase noise. ( DEPRECATED )

## Signals (sent with e.g. kill command) (http://www.lavrsen.dk/foswiki/bin/view/Motion/SignalsKill)

A signal can be sent from the command line by typing e.g. kill -s SIGHUP pid, where the last parameter is the process ID which you get by typing ps -ef ¦ grep motion. The PID is the first on the list which is the parent process for the threads. Motion responds to the following signals:

Signal (http://www.lavrsen.dk/foswiki/bin/view/Motion/MotionGuideOneLargeDocument;sortcol=0;table=10;up=0) | Description (http://www.lavrsen.dk/foswiki/bin/view/Motion/MotionGuideOneLargeDocument;sortcol=1;table=10;up=0) | Editors comment (http://www.lavrsen.dk/foswiki/bin/view/Motion/MotionGuideOneLargeDocument;sortcol=2;table=10;up=0)
SIGHUP | The config file will be reread. | This is a very useful signal when you experiment with settings in the config file.
SIGTERM | If needed motion will create an mpeg file of the last event and exit
SIGUSR1 | Motion will create an mpeg file of the current event.

## Error Logging (http://www.lavrsen.dk/foswiki/bin/view/Motion/ErrorLogging)

Motion reports errors to the console when it runs in non-daemon mode. And it outputs even more information when run in setup mode.

Error logging has been implemented so that errors during daemon (background) mode are logged in the syslog.

The syslog is in most Linux systems the file /var/log/messages (e.g. RedHat/Fedora) or /var/log/syslog and /var/log/user.log (e.g. Debian).

# Motion Guide - Basic Features

## Capture Device Options - The Basic Setup (http://www.lavrsen.dk/foswiki/bin/view/Motion/CaptureDeviceOptions)

Before you can start using motion you need to know some basics about your camera. Either you have a camera connected directly to your computer. In this case it is a video4linux type of camera. Or you connect to a network camera using a normal web URL.

## video4linux (V4L (http://www.lavrsen.dk/foswiki/bin/view/Motion/V4L)) devices

You need to install your camera with the right driver. It is out of scope of this document to tell you how to do this and it depends on which type of camera.

Once installed the camera(s) will have the device names /dev/video0, /dev/video1, /dev/video2...

FreeBSD has a different naming of devices. When you build Motion for FreeBSD the default device name is /dev/bktr0. Under FreeBSD a TV card has a special device for controlling the tuner (e.g. /dev/tuner0). The option tunerdevice is only valid when Motion is built and running under FreeBSD. For Linux do not include this option in the config file (remove or comment out).

USB cameras take a lot of bandwidth. A USB camera connected to a USB 1.1 port or hub consumes all the bandwidth. Even with a small framesize and low framerate you should not expect to have more than one camera per USB 1.1 controller. If you need more than 1 USB camera add extra USB PCI cards to your computer. There exists cards that have 4 inputs each with their own controller and with full bandwidth. Many 4-input cards only have 1 controller. USB cameras do not have the feature of selecting input channels. To disable the input selection the option input (http://www.lavrsen.dk/foswiki/bin/view/Motion/ConfigOptionInput) must be set to the value 8 for USB cameras.

Composite video cards are normally made with a chip called BT878 (older cards have a BT848). They all use the Linux driver called 'bttv'.

There are cards with more then one video input but still only one BT878 chip. They have a video multiplexer which input is selected with the config option input (http://www.lavrsen.dk/foswiki/bin/view/Motion/ConfigOptionInput). Input channel numbers start at 0 (which is why the value 8 and not 0 disables input selection). There are video capture cards available with 4 or 8 inputs but only one chip. They present themselves as one single video device and you select input using the 'input' option. If you define e.g. 4 thread config files with the same videodevice name but different input numbers Motion automatically goes into round robin mode. See the round robin (http://www.lavrsen.dk/foswiki/bin/view/Motion/MotionGuideOneLargeDocument#RoundRobin) section for more information. Many TV tuner cards have the input channels: TV Tuner = 0, Standard composite video = 1, S-VHS = 3. Other have TV=0, composite video 1= 1, composite video = 2, S-VHS = 3. For video capture cards input 1 is normally the composite video input.

Some capture cards are specially made for surveillance with for example 4 inputs. Others have a TV tuner, a composite input (phono socket) and perhaps also a S-VHS input. For all these cards the inputs are numbered. The numbering varies from card to card so the easiest is to experiment for 5 minutes with a program that can show the videostream. Use a program such as Camstream or xawtv to experiment with the values.

If you use the TV tuner input you also need to set the frequency of the TV channel using the option frequency (http://www.lavrsen.dk/foswiki/bin/view/Motion/ConfigOptionFrequency). Otherwise set 'frequency' to 0.

Finally you need to set the TV norm. Values: 0 (PAL), 1 (NTSC), 2 (SECAM), 3 (PAL NC no colour). Default is 0 (PAL). If your camera is a PAL black and white you may get a better result with norm=3 (PAL no colour).

If the netcam_url (http://www.lavrsen.dk/foswiki/bin/view/Motion/ConfigOptionNetcamUrl) option is defined all the video4linux options are ignored so make sure the netcam_url option is commented out if you do not need it.

These are the parameters used for video4linux devices

### auto_brightness

- Type: Boolean
- Range / Valid values: on, off
- Default: off
- Option Topic (http://www.lavrsen.dk/foswiki/bin/view/Motion/ConfigOptionAutoBrightness)

Let motion regulate the brightness of a video device. Only recommended for cameras without auto brightness

Motion will try to adjust the brightness of the video device if the images captured are too dark or too light. This option will be most useful for video devices like web cams, which sometimes don't have such an option in hardware.

The auto_brightness feature will adjust the brightness of the device up or down until the value defined by the option brightness (http://www.lavrsen.dk/foswiki/bin/view/Motion/ConfigOptionBrightness) is reached (1 = dark, 255 = bright). If brightness (http://www.lavrsen.dk/foswiki/bin/view/Motion/ConfigOptionBrightness) is zero auto_brightness will try to adjust to the average brightness level 128.

You need to know if the camera supports auto brightness. Most cameras have auto everything. If your video device already does this for you this option might cause oscillations. If you do not know assume that it has and do not use the Motion auto brightness feature. At least not to start with.

### brightness

- Type: Integer
- Range / Valid values: 0 - 255
- Default: 0 (disabled)
- Option Topic (http://www.lavrsen.dk/foswiki/bin/view/Motion/ConfigOptionBrightness)

The brightness level for the video device.

Value 0 means that Motion does not set the brightness value but leaves it unchanged.

If this setting is used in conjunction with the auto_brightness (http://www.lavrsen.dk/foswiki/bin/view/Motion/ConfigOptionAutoBrightness) feature then this setting is the average brightness level in the range 1 (dark) to 255 (bright) that the auto_brightness feature will try to achieve by adjusting the device brightness up and down.

### contrast

- Type: Boolean
- Range / Valid values: 0 - 255
- Default: 0 (disabled)
- Option Topic (http://www.lavrsen.dk/foswiki/bin/view/Motion/ConfigOptionContrast)

The contrast level for the video device.

Disabled (Value 0) means that Motion does not set the contrast value.

### framerate

- Type: Integer
- Range / Valid values: 2 - 100
- Default: 100 (no limit)
- Option Topic (http://www.lavrsen.dk/foswiki/bin/view/Motion/ConfigOptionFramerate)

Maximum number of frames to be captured from the camera per second.

The faster you fetch pictures from the camera the more CPU load you get and the more pictures get included when Motion is detected.

Motion will stop storing pictures if the framerate is set to less than 2.

Set this parameter to the maximum number of images per second that you want to store either as images or as mpeg films.

To set intervals longer than one second use the 'minimum_gap' option instead.

### frequency

- Type: Boolean
- Range / Valid values: 0 - 999999
- Default: 0 (Not set)
- Option Topic (http://www.lavrsen.dk/foswiki/bin/view/Motion/ConfigOptionFrequency)

The frequency to set the tuner to (kHz). Valid range: per tuner spec, default: 0 (Don't set it)

This option is only relevant if you have a TV tuner card where you can select the tuner frequency. Your tuner card must support this feature.

### height

- Type: Integer
- Range / Valid values: Device Dependent
- Default: 288
- Option Topic (http://www.lavrsen.dk/foswiki/bin/view/Motion/ConfigOptionHeight)

The height of each frame in pixels.

The height of the image in pixels. Motion does not scale so should be set to the actual size of the v4l device. In case of a net camera motion sets the height to the height of the first image read.

Motion actually set the size of the image coming from the video4linux device.

Your camera or capture/TV card will not support any picture size. You must know which frame size (width and height) the camera supports. If you do not know start with width 320 and height 240 which most cameras and capture cards supports.

For some device drivers like pwc (driver for Philips USB cameras) setting the size to a non-standard value makes the driver create an image of the nearest smaller size and create a gray band around the image to fit the size given by motion. Note that it is the driver and not motion that generates the gray band. Motion will try to detect motion in the entire image including the gray band.

Motion requires that dimensions of camera image must have both height and width that are a multiple of 16. Thís is normally not a problem. All standard sizes like 640, 480, 352, 320, 288, 240, ...etc are multiples of 16.

### hue

- Type: Integer
- Range / Valid values: 0 - 255
- Default: 0 (disabled)
- Option Topic (http://www.lavrsen.dk/foswiki/bin/view/Motion/ConfigOptionHue)

The hue level for the video device.

Normally only relevant for NTSC cameras.

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

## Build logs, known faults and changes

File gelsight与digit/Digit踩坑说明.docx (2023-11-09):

Digit踩坑说明

一、PCB制板

注：可以考虑嘉立创，目前实验室Digit和Digit-Flex均有已经加工好未贴片的PCB板

Digit：

问题记录：

1、材料选择FR4，嘉立创返单说明：（问题来源：嘉立创）

Digit-Flex：

问题记录：

1、官方开源的digit-flex文件中，assembly和gerber文件夹中均有gerber文件，其中gerber文件夹中标识电路走线，assembly文件夹标识安装情况，为了安装方便，开源文件要求在Digit-flex板无灯珠的面补强3M胶，使得FPC软板能够与3D打印外壳固定，此步可要求嘉立创完成

2、嘉立创在加工该文件时强制要求拼版，理由：所加工的板子太小，建议看看能不能不拼，可以省钱

3、电话联系，具体问题记不太清了，大致内容：开源Digit-flex中过孔（可能是，不太记得了）与常规工艺不太相符，可能造成一定的问题（问题来源：嘉立创）

二、元件购买

注：

常见元件：可以直接替换，只要参数大致相同

非常见元件：可以接受长时间等待：可以海外代购

不能接受长时间等待：淘宝一家家问吧，要接受涨价和起订数

购买时建议先联系商家确定商家有货再下单！！！

注：所有链接，均不保证有货

Digit：见digit元件选择.xls

Digit-Flex：见digit-flex元件选择.xls

问题记录：

1、收到邮寄元件确认信息（问题来源：嘉立创）：

编号（C4355529）对应的器件丝印是（FT900Q-C-T），收到实物丝印是（FT900Q），售卖者表示正版

编号（C232592）对应的器件丝印是（BC847CDXV6T1G），收到实物丝印是（1GY）

编号（C125810）对应的器件丝印是（LP3992IMFX-1.5/NOPB），收到实物丝印是（LFHB）

是否会带来问题建议查实

三、元件贴片

注：建议优化元件贴片步骤：

本次采用方法：digit板嘉立创SMT贴片、digit-flex板南京本地加工商手工焊接

本地加工商手工焊接原因：digit-flex共6个元件，SMT贴片价格较高，但是焊接工人也反映芯片引脚小容易出错

对于是否之后要在嘉立创SMT贴片建议与本地加工商询价后再决定，本次SMT贴片710.51，手工焊接200，曾经询价某非南京本地淘宝PCB加工厂商，其不支持PCB加工时提前备元件材料，工期比较长，价格和嘉立创感觉差不太多

SMT需要提供芯片对应的xy坐标和bom表，该部分需要使用开源文档根据嘉立创要求进行修改。开源文档中xy坐标单位为mil，嘉立创只接受mm，需要转换

嘉立创有最小起贴片数！！

问题记录：

1、X1位置元器件引脚与焊盘引脚间距相差0.2mm，后果会移位和虚焊（问题来源：嘉立创）

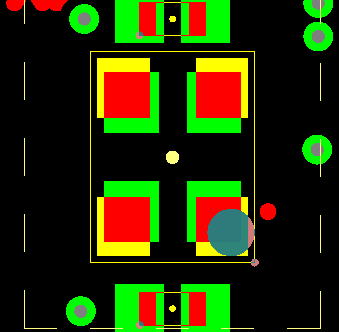
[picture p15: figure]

写总结文档时发现的问题：X1元件选型可能出错！！！！！！！！！

Digit Bom表第22行：

其中：

ABM10-25.000MHZ-D30-T3：

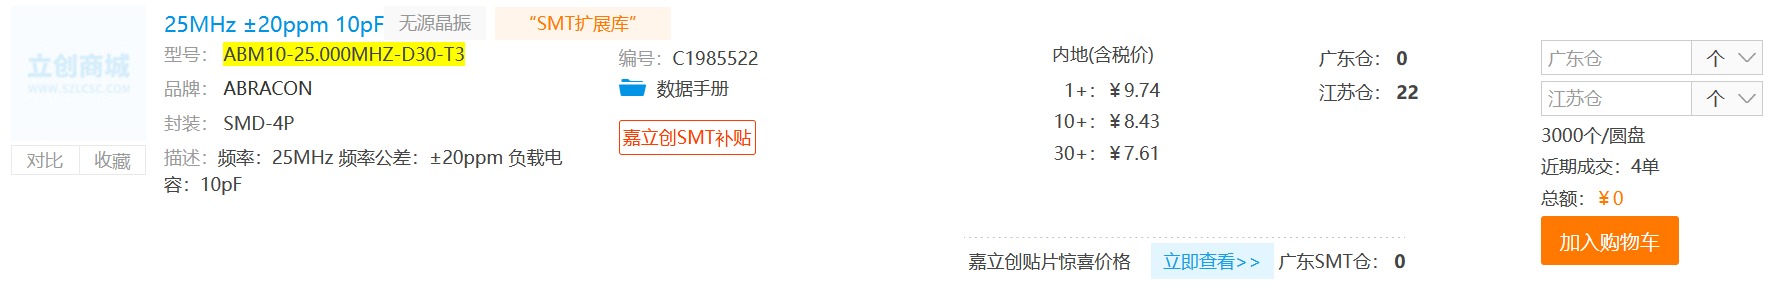
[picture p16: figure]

ECS-120-18-36-AGM-TR：

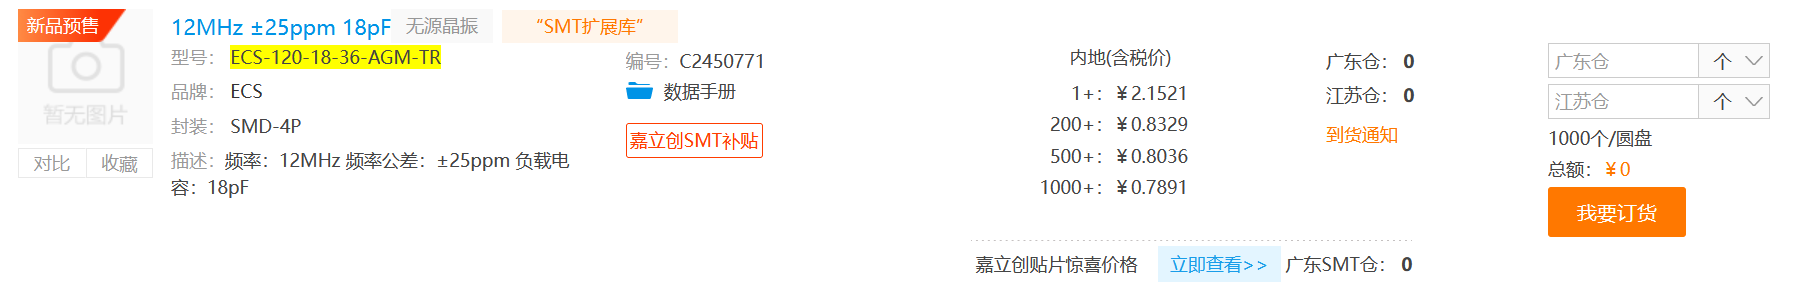
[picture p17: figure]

最前列和最后列所写内容存在出入，嘉立创读取BOM表时根据ABM10-25.000MHZ-D30-T3进行推荐，手动校核也没看出来，最终贴片也采用了ABM10-25.000MHZ-D30-T3的替代品，建议查看实际gerber文件看具体选用了哪款元件。

相差0.2mm：可能由于ABM10-25.000MHZ-D30-T3的替代品封装为SMD3225-4P，ABM10-25.000MHZ-D30-T3与ECS-120-18-36-AGM-TR均为SMD-4P有关

2、U2位置元器件引脚与焊盘引脚间距相差0.2mm，后果会移位和虚焊（问题来源：嘉立创）

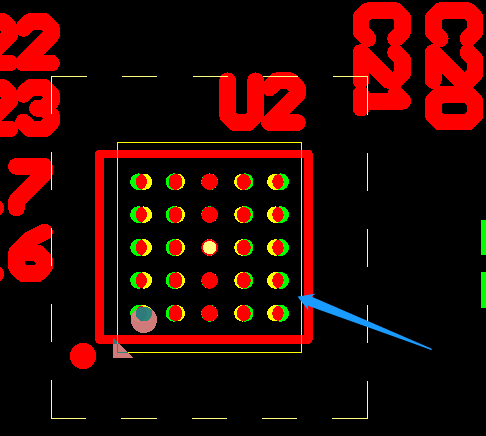
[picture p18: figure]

该元件为摄像头元件，建议查看开源网站中提示摄像头可进行替换一事，是否对此问题产生影响。本次制板选用开源文件中DIGIT-fab-release-2020-2，摄像头型号为OVM7692-RAAA

3、需要确定U2元件中A1引脚的位置（问题来源：嘉立创）

由于OVM7692-RAAA存在一面与其他三面不同的情况，所以可以通过实物进行判断

注：OVM7692-RAAA的生产厂家豪威集团omnivision不为不直接从其手中购买芯片的用户提供数据手册和技术支持，同时从其和经销商手中购买也有起订量，如果实在需要数据手册，可以试试豪威集团有一个代理，在南京有分公司，但是电话一直没打通，可能也要不到，只能说试试

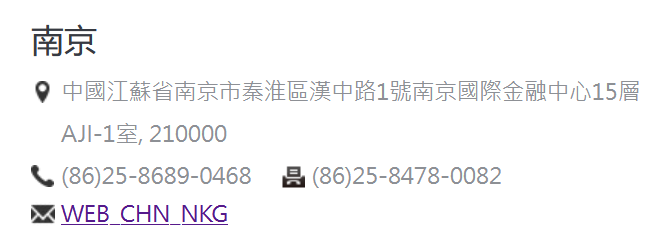
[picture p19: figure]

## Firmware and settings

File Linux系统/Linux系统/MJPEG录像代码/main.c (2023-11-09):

#include <stdio.h>
#include <stdlib.h>
#include <unistd.h>
#include <sys/types.h>
#include <sys/stat.h>
#include <sys/file.h>
#include <string.h>
#include <pthread.h>
#include <linux/videodev2.h>
#include <sys/ioctl.h>
#include <sys/mman.h>
#include <errno.h>
#include <fcntl.h>
#include <time.h>
#include <sys/time.h>
#include <signal.h>
#include <X11/Xlib.h>
#include "v4l2uvc.h"
#include "avilib.h"

int main(int argc, char *argv[])   // -s 1280x720   -d  /dev/video1   -a  test.avi  -i 30
{
	FILE *file = NULL;
	struct vdIn *vd;
	unsigned char *tmpbuffer;
	char *filename = NULL;
	char *avifilename = NULL;
	
	char *sizestring = NULL;
	char *fpsstring  = NULL;
	char *separateur = NULL;
	int width ; 
	int height;
	int fps;
	int i;
		
	for (i = 0; i < argc; i++) 
	{		
		printf("No ffff %d\n" ,argc);
		if (1 == argc)
		{
			printf("No for for \n");
			
		    width = 640 ; 
	        height = 480 ;
	        fps   = 30 ;
	        filename = "/dev/video2";
	        avifilename = "test.avi";
		}
		
		if (argv[i] == NULL || *argv[i] == 0 || *argv[i] != '-') 
		{
			continue;
		}
		
		if (strcmp(argv[i], "-s") == 0) 
		{
			if (i + 1 >= argc) 
			{
				printf("No parameter specified with -s, aborting.\n");
				exit(1);
			}

			sizestring = strdup(argv[i + 1]);

			width = strtoul(sizestring, &separateur, 10);
			if (*separateur != 'x') 
			{
				printf("Error in size use -s widthxheight\n");
				exit(1);
			} 
			else 
			{
				++separateur;
				height = strtoul(separateur, &separateur, 10);
				if (*separateur != 0)
					printf("hmm.. dont like that!! trying this height\n");
			}
		}
		else 
		{
			width = 640; 
	        height = 480;
		}
		
		if (strcmp(argv[i], "-d") == 0) 
		{
			if (i + 1 >= argc) 
			{
				printf("No parameter specified with -d, aborting.\n");
				exit(1);
			}
			filename = strdup(argv[i + 1]);
			
		}
		
		if (strcmp(argv[i], "-a") == 0) 
		{
			if (i + 1 >= argc) 
			{
				printf("No parameter specified with -o, aborting.\n");
				exit(1);
			}
			avifilename = strdup(argv[i + 1]);
		}
		
		if (strcmp(argv[i], "-i") == 0)
		{
			if (i + 1 >= argc) 
			{
				printf("No parameter specified with -i, aborting.\n");
				exit(1);
			}
			fpsstring = argv[i + 1];
			fps = strtoul(fpsstring, &separateur, 10);
			if(*separateur != '\0') 
			{
				printf("Invalid frame rate '%s' specified with -i. "
						"Only integers are supported. Aborting.\n", fpsstring);
				exit(1);
			}
		}
		else 
		{
			fps = 30;
		}
		
	}
	
	if (filename == NULL || *filename == 0) {		
		filename = "/dev/video0";
	}

	if (avifilename == NULL || *avifilename == 0) {
		avifilename = "test.avi";
	}
	
	int format = V4L2_PIX_FMT_MJPEG;
	int ret;
	int grabmethod = 1;
		
	file = fopen(filename, "wb");
	if(file == NULL) 
	{
		printf("Unable to open file for raw frame capturing\n ");		
		exit(1);
	}
	
	//v4l2 init
	vd = (struct vdIn *) calloc(1, sizeof(struct vdIn));
	if(init_videoIn(vd, (char *) filename, width, height,fps,format,grabmethod,avifilename) < 0)
	{
		exit(1);
	}
	
	if (video_enable(vd))
	{
	   exit(1);
	}
	
	vd->avifile = AVI_open_output_file(vd->avifilename);
	if (vd->avifile == NULL ) 
	{
		printf("Error opening avifile %s\n",vd->avifilename);
		exit(1);
	}
	
	AVI_set_video(vd->avifile, vd->width, vd->height, fps, "MJPG");
	printf("recording to %s\n",vd->avifilename);

	while(1)
	{		
		memset(&vd->buf, 0, sizeof(struct v4l2_buffer));
		vd->buf.type = V4L2_BUF_TYPE_VIDEO_CAPTURE;
		vd->buf.memory = V4L2_MEMORY_MMAP;
		ret = ioctl(vd->fd, VIDIOC_DQBUF, &vd->buf);
		if (ret < 0) 
		{
			printf("Unable to dequeue buffer");
			exit(1);
		}
		
		memcpy(vd->tmpbuffer, vd->mem[vd->buf.index],vd->buf.bytesused);
	
		AVI_write_frame(vd->avifile, vd->tmpbuffer,vd->buf.bytesused, vd->framecount);
	
		vd->framecount++;
		
		ret = ioctl(vd->fd, VIDIOC_QBUF, &vd->buf);
		if (ret < 0||vd->framecount==90) 
		{
			printf("Unable to requeue buffer");
			exit(1);
		}
	}
	fclose(file);
	close_v4l2(vd);
}

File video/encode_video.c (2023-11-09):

#include <string.h>
#include <time.h>
#include <unistd.h>

#include "libavdevice/avdevice.h"
#include "libavformat/avformat.h"
#include "libavutil/avutil.h"

#define V_WIDTH 1280
#define V_HEIGHT 720
#define FRAMES 90

void create_time_command(char command[]){
    time_t tt = time(0);
    char s[32];
    strftime(s, sizeof(s), "%02m%02d_%02H%02M%02S", localtime(&tt));
    sprintf(command,"MP4Box -add video.h264 -fps 30 ./result/out%s.mp4",s);
}

//@brief
// return
static AVFormatContext *open_dev() {
    int ret = 0;
    char errors[1024] = {
        0,
    };

    // ctx
    AVFormatContext *fmt_ctx = NULL;
    AVDictionary *options = NULL;

    //摄像头的设备文件
    char *devicename = "/dev/video6";

    // register video device 
    avdevice_register_all();

    // get format
    AVInputFormat *iformat = av_find_input_format("video4linux2");

    av_dict_set(&options, "video_size", "1280x720", 0);
    av_dict_set(&options, "framerate", "30", 0);
    av_dict_set(&options, "pixel_format", "yuyv422", 0);

    // open device
    ret = avformat_open_input(&fmt_ctx, devicename, iformat, &options);
    if (ret < 0) {
        av_strerror(ret, errors, 1024);
        fprintf(stderr, "Failed to open video device, [%d]%s\n", ret, errors);
        return NULL;
    }

    return fmt_ctx;
}

static void open_encoder(int width, int height, AVCodecContext **enc_ctx) {
    int ret = 0;
    AVCodec *codec = NULL;
    //新版本无需调用
    //avcodec_register_all();

    codec = avcodec_find_encoder_by_name("libx264");
    if (!codec) {
        printf("Codec libx264 not found\n");
        exit(1);
    }

    *enc_ctx = avcodec_alloc_context3(codec);
    if (!enc_ctx) {
        printf("Could not allocate video codec context!\n");
        exit(1);
    }

    // SPS/PPS
    (*enc_ctx)->profile = FF_PROFILE_H264_HIGH_444;
    (*enc_ctx)->level = 50; //表示LEVEL是5.0

    //设置分辫率
    (*enc_ctx)->width = width;   // 640
    (*enc_ctx)->height = height; // 480

    // GOP
    (*enc_ctx)->gop_size = 250;
    (*enc_ctx)->keyint_min = 25; // option

    //设置B帧数据
    (*enc_ctx)->max_b_frames = 3; // option
    (*enc_ctx)->has_b_frames = 1; // option

    //参考帧的数量
    (*enc_ctx)->refs = 3; // option

    //设置输入YUV格式
    (*enc_ctx)->pix_fmt = AV_PIX_FMT_YUV420P;

    //设置码率
    (*enc_ctx)->bit_rate = 600000; // 600kbps

    //设置帧率
    (*enc_ctx)->time_base = (AVRational){1, 30}; //帧与帧之间的间隔是time_base
    (*enc_ctx)->framerate = (AVRational){30, 1}; //帧率，每秒 30帧

    ret = avcodec_open2((*enc_ctx), codec, NULL);
    if (ret < 0) {
        printf("Could not open codec: %s!\n", av_err2str(ret));
        exit(1);
    }
}

static AVFrame *create_frame(int width, int height) {
    int ret = 0;
    AVFrame *frame = NULL;

    frame = av_frame_alloc();
    if (!frame) {
        printf("Error, No Memory!\n");
        goto __ERROR;
    }

    //设置参数
    frame->width = width;
    frame->height = height;
    frame->format = AV_PIX_FMT_YUV420P;

    // alloc inner memory
    ret = av_frame_get_buffer(frame, 32); //按 32 位对齐
    if (ret < 0) {
        printf("Error, Failed to alloc buffer for frame!\n");
        goto __ERROR;
    }

    return frame;

__ERROR:
    if (frame) {
        av_frame_free(&frame);
    }

    return NULL;
}

static void encode(AVCodecContext *enc_ctx, AVFrame *frame, AVPacket *newpkt,
                   FILE *outfile) {
    int ret = 0;
    if (frame) {
        //printf("send frame to encoder, pts=%ld", frame->pts);
    }
    //送原始数据给编码器进行编码
    ret = avcodec_send_frame(enc_ctx, frame);
    if (ret < 0) {
        printf("Error, Failed to send a frame for enconding!\n");
        exit(1);
    }

    //从编码器获取编码好的数据
    while (ret >= 0) {
        ret = avcodec_receive_packet(enc_ctx, newpkt);

        //如果编码器数据不足时会返回  EAGAIN,或者到数据尾时会返回 AVERROR_EOF
        if (ret == AVERROR(EAGAIN) || ret == AVERROR_EOF) {
            return;
        } else if (ret < 0) {
            printf("Error, Failed to encode!\n");
            exit(1);
        }

        fwrite(newpkt->data, 1, newpkt->size, outfile);
        fflush(outfile);
        av_packet_unref(newpkt);
    }
}

void yuyv422ToYuv420p(AVFrame *frame, AVPacket *pkt) {
    int i = 0;
    int yuv422_length = V_WIDTH * V_HEIGHT * 2;
    int y_index = 0;
    // copy all y
    for (i = 0; i < yuv422_length; i += 2) {
        frame->data[0][y_index] = pkt->data[i];
        y_index++;
    }

    // copy u and v
    int line_start = 0;
    int is_u = 1;
    int u_index = 0;
    int v_index = 0;
    // copy u, v per line. skip a line once
    for (i = 0; i < V_HEIGHT; i += 2) {
        // line i offset
        line_start = i * V_WIDTH * 2;
        for (int j = line_start + 1; j < line_start + V_WIDTH * 2; j += 4) {
            frame->data[1][u_index] = pkt->data[j];
            u_index++;
            frame->data[2][v_index] = pkt->data[j + 2];
            v_index++;
        }
    }
}

void rec_video() {
    int ret = 0;
    int base = 0;
    int count = 0;
    int frame_index = 0;
    int64_t calc_duration = 0;
    // pakcet
    AVPacket pkt;
    AVFormatContext *fmt_ctx = NULL;
    AVCodecContext *enc_ctx = NULL;

    // set log level
    av_log_set_level(AV_LOG_DEBUG);

    // create file
    char *yuvout = "./video.yuv";
    char *out = "./video.h264";

    FILE *yuvoutfile = fopen(yuvout, "wb+");
    FILE *outfile = fopen(out, "wb+");

    //打开设备
    fmt_ctx = open_dev();

    //打开编码器
    open_encoder(V_WIDTH, V_HEIGHT, &enc_ctx);
    
    calc_duration = (double)AV_TIME_BASE / av_q2d((*enc_ctx).framerate);

    //创建 AVFrame
    AVFrame *frame = create_frame(V_WIDTH, V_HEIGHT);

    //创建编码后输出的Packet
    AVPacket *newpkt = av_packet_alloc();
    if (!newpkt) {
        printf("Error, Failed to alloc avpacket!\n");
        goto __ERROR;
    }

    // read data from device
    while (((ret = av_read_frame(fmt_ctx, &pkt)) == 0) && (count++ < FRAMES)) { 
        int i = 0;
        //av_log(NULL, AV_LOG_INFO, "packet size is %d(%p)\n", pkt.size,
        //       pkt.data);

        // YUYVYUYVYUYVYUYV   YUYV422
        // YYYYYYYYUUVV YUV420
        yuyv422ToYuv420p(frame, &pkt);

        fwrite(frame->data[0], 1, 307200, yuvoutfile);
        fwrite(frame->data[1], 1, 307200 / 4, yuvoutfile);
        fwrite(frame->data[2], 1, 307200 / 4, yuvoutfile);

        frame->pts = base++;
        
        
        if(newpkt->pts == AV_NOPTS_VALUE) {
          //Write PTS
          AVRational time_base1 =  (*enc_ctx).time_base;
          //Duration between 2 frames (us)
          //Parameters
          newpkt->pts = (double)(frame_index*calc_duration) / (double)(av_q2d(time_base1)*AV_TIME_BASE);
          newpkt->dts = newpkt->pts;
          newpkt->duration = (double)calc_duration / (double)(av_q2d(time_base1)*AV_TIME_BASE);
          frame_index++;
        }
        encode(enc_ctx, frame, newpkt, outfile);
        //
        av_packet_unref(&pkt); // release pkt
    }

    encode(enc_ctx, NULL, newpkt, outfile);
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
